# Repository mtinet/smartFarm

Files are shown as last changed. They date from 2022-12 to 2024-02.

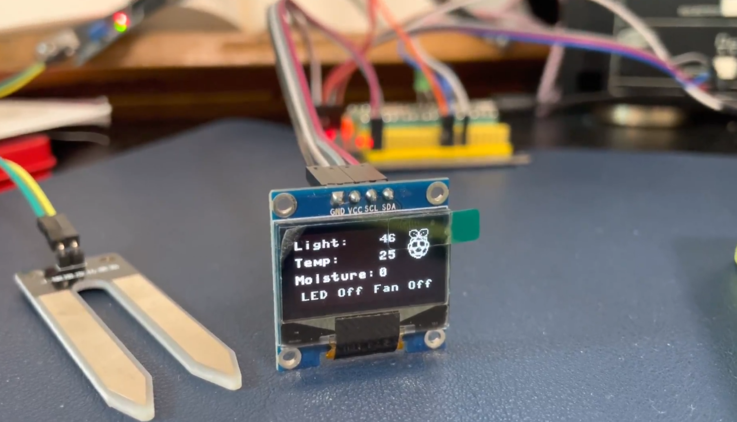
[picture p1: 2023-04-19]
0. image/testImage.png

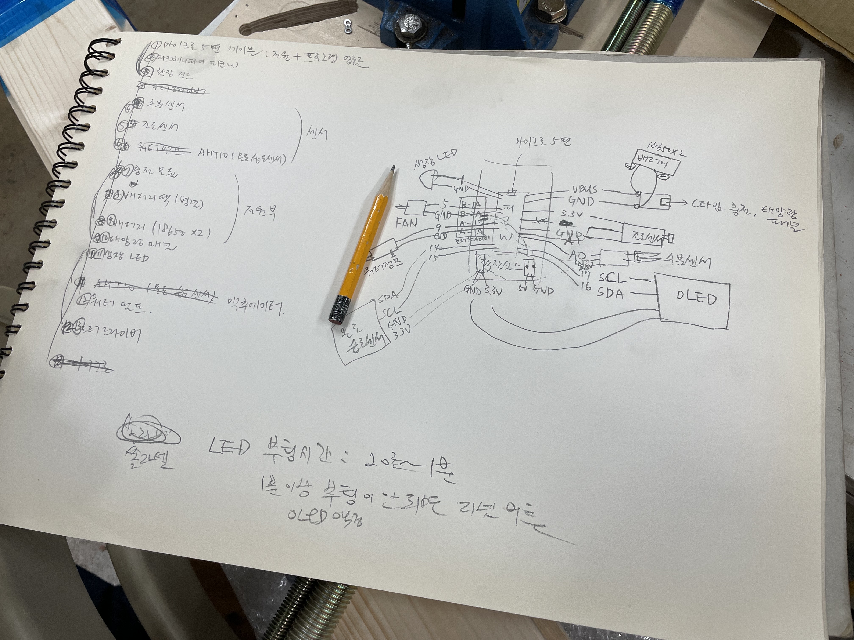
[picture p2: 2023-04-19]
0. image/design note.jpg

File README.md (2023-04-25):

# smartFarm
---

---
This code was written by Juhyun Kim.
---

## 강의 자료  
[http://han.gl/WLvoNj](http://han.gl/WLvoNj)  

---
## 구조
### Raspberry Pi Pico W - Firebase Realtime Database - Web or App  
#### 1. Firebase의 활용방법  
  

#### 2. 본 smartFarm의 운용 구조  


#### 3. 회로도  


---
---
## 각 세그먼트의 특징

### 1. Firebase  
#### 1. Firebase는 구글에서 운영하는 인터넷 관련 BaaS서비스라고 볼 수 있다. BaaS에 대한 정의는 [링크](https://blog.back4app.com/ko/%EC%84%9C%EB%B9%84%EC%8A%A4-%ED%98%95-%EB%B0%B1%EC%95%A4%EB%93%9Cbackend-as-a-service-baas%EB%8A%94-%EB%AC%B4%EC%97%87%EC%9D%B8%EA%B0%80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)를 참고한다. 각 온라인 서비스 프로바이더의 분류는 아래 그림을 참고하면 된다.  
  

#### 2. 우리가 스마트팜 프로젝트에서 Firebase를 사용하는 그 이유는 다음과 같다.  
* 첫째, 우리는 IPv4 시스템의 한계로 인해 개별 기기에 공인IP를 가질 수 없다.  
* 둘째, 이는 몇 개 안되는 공인IP 아래에 공유기를 연결해 사설 IP를 만들어내 사용해야 함을 의미한다.  
* 셋째, 사설 IP를 사용하는 디바이스가 운용하는 서비스에 접근하려면 네트워크의 개념을 이해하고 있어야 한다.
* 넷째, 이 중 가장 기본인 공인 IP에서 사설 IP로 연계를 하기 위한 과정인 포트포워딩에 대해 이해하고 있어야 한다.
* 다섯째, 모바일 통신에서는 각 모바일 통신사가 권한을 가지고 있는 모바일 통신망 NAT의 구조에 대해 이해하고 있어야 한다.
* 여섯째, 하지만 이를 도전한 사람들은 NAT를 통해 역으로 모바일 디바이스나 모바일 통신망을 통해 테더링을 하고 있는 디바이스에서 운용하는 서비스에 접근하는 것은 모바일 서비스를 제공하는 통신사의 권한부여 없이는 불가능하다는 사실을 수십 수백번의 시도 끝에 알게 된다. 통신사는 그걸 지원할 생각이 없다.
* 일곱째, 일반적으로 통신은 서버와 클라이언트로 구성되고, 서버가 서비스를 열면, 클라이언트가 접근하는 형태로 서비스가 되는데, 위의 설명과 같은 이유들로 서버가 서비스를 해도 클라이언트가 접근을 할 수가 없거나, 그 과정이 매우 어렵다는데 있다.
* 여덟째, 따라서, 우리는 구글 계정과 간단한 세팅만으로 쉽게 사용할 수 있는 Firebase라는 중간 단계의 Realtime Database 서비스를 이용해 이 곳에 데이터를 올리고, 이 곳에 접근해서 데이터를 읽어가는 형태의 서비스를 구상하게 된 것이다.
* 참고로, Firebase는 Realtime Database만 지원되는 것이 아니고, 인증, 앱체크, 데이터베이스, 스토리지, 호스팅, 함수 서비스, 머신러닝, 분석 등 엄청나게 다양한 서비스를 지원하고 있으며, 충분한 용량을 무료로 제공하므로, 개발단계나 테스트 단계에서는 무료라고 봐도 무방하다.
* 어쨌든 사람들이 해당 서비스를 사용하고, 그 서비스를 이용해 부가가치를 만들어내야 자신들도 먹고 살 수 있음을 잘 알고 있는 것이고, 그런 사람들이 많으면 많을수록 좋으니 이렇게 제공되는 기본 서비스들을 통해서 우리 같은 초보개발자들이 마음 놓고 테스트를 진행해볼 수 있다는 것이다.
* 이는 오픈소스 진영의 라이프사이클이 잘 돌아가고 있고, 그 안에 있는 사람들이 아직 건재하게 생존해 있다는 것으로 증명된 사실이며, 사실 구글도 그런 문화를 통해 성장해왔으니, 그런 서비스를 통해 자신들의 생태계를 더욱 확장하는 방법을 알고 있는 것은 어찌보면 매우 당연한 일이다.

---
### 2. Github Pages  
#### 1. Github는 전세계 코더들의 자료 저장소이며, 자신의 프로젝트들을 관리하고 공유할 수 있도록 서비스를 제공하고 있다.
#### 2. Github Pages는 HTML, CSS, JavaScript로 대변되는 정적 웹페이지에 대한 서비스를 무료로 제공하고 있다. 정적 웹페이지는 서버측에서 클라이언트의 특정한 요청에 대해 프로세스를 진행하고 그 결과물을 제공해주는 동적웹페이지(WAS서버, 데이터베이스, 로그인 기능 등이 추가됨)와 달리 단순히 웹페이지만 제공한다.
#### 3. 우리가 스마트팜 프로젝트에서 Github Pages를 사용하는 이유는 다음과 같다.
* 첫째, 이 프로젝트가 제공하는 것은 Firebase의 Realtime Database가 아니라 이를 활용하여 스마트팜의 정보를 지구 반대편에서도 확인하고 원격으로 제어할 수 있는 서비스이다.  
* 둘째, 서버에 클라이언트가 직접 접근할 수 있는 서비스가 가장 직관적이며 빠르지만, 서버를 스스로 구축하는 부분에 대한 개인 역량의 문제, 네트워크의 접근성 제약에 따른 한계 등 다양한 형태의 제약조건이 많으므로, 이를 극복하면서도 그럴싸한 서비스를 제공할 필요가 있다.  
* 셋째, Github Pages는 이러한 서비스를 제공하는데 가장 쉬운 서비스를 무료로 제공하고 있다.  
* 넷째, Github 자체는 전세계 사람들이 참여하고 있으므로, 이번 기회를 통해 이 생태계를 이해하게 된다면, 소프트웨어 관련 프로젝트를 진행할 때 든든한 지원군을 얻게 되는 셈이다.  
* 다섯째, 당연히 웹페이지도 무료로 배포되며, 자신만의 포트폴리오를 만들고 관리하는데 매우 훌륭한 도구이다.  
* 여섯째, 일단 웹페이지로 구현된 것은 WebViewer라는 기능을 통해 쉽게 앱으로도 구현할 수 있다.  
* 일곱째, 부수적으로 [W3Schools](https://www.w3schools.com/)등의 사이트를 Github와 함께 활용함으로써 웹을 이용한 서비스를 구축하는 다양한 방법들을 공부하고, 관련 역량을 키워나갈 수 있다.  

---
### 3. Raspberry Pi Pico W  
#### 1. Raspberry Pi Pico W는 아두이노 우노에 대응하는 라즈베리파이 재단의 피지컬 컴퓨팅 도구인 라즈베리파이 피코의 와이파이 버전이다.  
##### * [PicoW-A4-Pinout.pdf](https://github.com/mtinet/smartFarm/files/10328225/PicoW-A4-Pinout.pdf)  
##### * [핀 설명 자료](https://www.mischianti.org/2022/09/16/raspberry-pi-pico-w-high-resolution-pinout-and-specs/)  
##### * [Pico W 활용방법](https://make.e4ds.com/contest/board_view.asp?t=2&idx=653&ctidx=8)  
  

  

#### 2. 파이썬을 활용하므로 프로그래밍과 관련 생태계에 쉽게 접근이 가능하다.  
#### 3. 우리가 스마트팜 프로젝트에서 Raspberry Pi Pico W를 사용하는 이유는 다음과 같다.
* 첫째, 다른 라즈베리파이가 라즈비안이라는 리눅스 OS를 사용하는 컴퓨터(MPU, 마이크로 프로세서 유닛을 사용하는)인 반면에 피코는 펌웨어(파이썬 펌웨어, 자바스크립트 펌웨어 등)를 올려서 주로 피지컬 컴퓨팅용으로 사용하는 장비(MCU, 마이크로 컨트롤러를 사용하는)이다. 이는 아두이노 우노와 같은 반복적인 일을 하는데 최적화 되어 있음을 의미한다.
* 둘째, 아두이노 우노와의 차이점은 아두이노 우노의 경우 C, C++을 사용하므로 가볍게 사용할 수 있지만, 사용 언어가 요즘 세대에게 익숙하지 않다는 점이 있는데 반해 라즈베리파이 피코의 경우 어떤 펌웨어를 업로드 하느냐에 따라 마이크로 파이썬이나 자바스크립트 등을 선택해서 사용할 수 있고, 상대적으로 고급 언어를 사용할 수 있다는 점이 장점이다.
* 셋째, 마이크로 파이썬을 사용할 경우 [https://micropython.org/download/rp2-pico-w/](https://micropython.org/download/rp2-pico-w/) 링크에서 최신 버전을 다운로드 받은 다음 피코에 업로드 하면 된다. 업로드는 피코의 Bootsel 버튼을 누른 상태에서 컴퓨터에 USB케이블을 꽂으면 피코가 외장 디스크로 인식이 되고, 내 컴퓨터에서 다운로드 받은 펌웨어 파일을 업로드 하기만 하면 된다.
* 넷째, Pico W는 마이크로 컨트롤러이지만 WiFi모듈이 실장되어 있어, 주변에 와이파이 공유기가 있다면, 바로 공유기(2.4GHz)에 접속해 인터넷과 연결할 수 있다.  
* 다섯째, 조도, 온도, 습도 센서를 비롯한 다양한 형태의 센서로부터 값을 받아와서 Firebase로 전송이 가능하므로, 어떤 장치를 만들더라도 해당 시스템만 이해하고 있으면 확장이 가능하다.  
* 여섯째, 반도체 이슈 이후로 각 싱글보드 컴퓨터의 가격이 폭등하였는데, 피코는 여전히 저렴하다. 일반 피코는 4달러, 피코 W는 6달러 수준이고, 국내에서도 큰 차이 없이 구매할 수 있으므로, 더욱 매력적이다.  
* 일곱째, 블루투스를 이용한 스마트팜은 근거리에서만 활용이 가능하며 진정한 의미의 IoT라고 볼 수 없는데, 피코 W는 이점을 굉장히 쉬운 방법으로 극복할 수 있으며, ESP32, ESP8266보드에 비해서 사용성이 용이하다.

---
---
## 세그먼트 간 통신 테스트 영상

### Raspberry Pi Pico - Firebase - Github Pages(P5js)

#### 1. 웹페이지를 Github Pages에 올려 구동을 한 후 Firebase와 통신이 잘되는지 테스트  
https://user-images.githubusercontent.com/13882302/210140386-bab783f3-679c-4fcc-b290-30dfc66772a5.mp4

#### 2. P5js, Github Pages, Android WebViewer로 각각 접속하여 제어하는 테스트  
KakaoTalk_20221231_232533880  

https://user-images.githubusercontent.com/13882302/210140510-c865a007-dc22-45c3-a544-d3b83081fc7e.mp4

### Raspberry Pi Pico - Firebase - Github Pages(Gauge)
#### 1. Firebase - Github Pages  
https://user-images.githubusercontent.com/13882302/210126670-243a6fd7-b9b9-4378-b12e-63e5b2ef9260.mp4

#### 2. Raspberry Pi Pico W - Firebase - Github Pages 상호 연동 전체 테스트(센서 실측, 실물 액츄에이터 제어만 빠진 상태)  
https://user-images.githubusercontent.com/13882302/210160212-4c1c4434-d080-4d26-9ced-889305b29337.mp4  

#### 3. Pico에 연결되어 있는 엘이디의 초록색은 LED On, Fan Off, 하늘색은 LED On, Fan On, 파란색은 LED Off, Fan On, 꺼지면 LED Off, Fan Off
https://user-images.githubusercontent.com/13882302/210160762-b4973f54-8970-44d7-9b3c-84a1720f3988.mp4  

---
---
## 세팅

### 1.Firebase 세팅
#### 1. 아래 링크로 이동해서 구글 계정으로 로그인을 하고, 오른쪽 상단에 있는 '콘솔로 이동' 버튼을 눌러 Firebase 콘솔로 들어간다.  
[https://firebase.google.com/](https://firebase.google.com/)  


#### 2. '프로젝트 추가'버튼을 눌러 자신의 프로젝트를 만든다.  
  
  

#### 3. 데이터 분석을 하지 않을 경우 Google 애널리틱스 사용 설정을 해제하고 '프로젝트 만들기'버튼을 누른다.  
  
  

#### 4. 30초 정도 프로젝트 생성 시간을 기다린다.  
  
  
  

#### 5. 새로 만든 프로젝트 폴더로 들어간다.  
  

#### 6. Firebase 메뉴중에서 빌드-Realtime Database를 선택해서 연다.  
화면 캡처 2022-12-31 160136  

#### 7. '데이터베이스 만들기' 버튼을 누른다.  
  

#### 8. 서버 위치를 선택한다.  
  

#### 9. 데이터베이스 기본 설정을 한다. 추후 언제나 바꿀 수 있으니 기본 세팅으로 사용설정을 한다.  
  

#### 10. 가운데 있는 링크를 통해 Realtime Database에 접근을 할 수 있다.  
  

#### 11. '규칙' 탭으로 들어오면 데이터베이스에 대한 읽기, 쓰기 권한이 설정되어 있는데, 이 설정이 매우 중요하다.  
  

#### 12. false로 기본 설정되어 있는데, 이곳을 클릭하여 true로 바꿔주고 '게시'버튼을 누르면 누구나 접근해서 데이터를 읽고 쓸 수 있다. 추후 보안 및 트래픽에 따른 결제비용 증가에 영향을 줄 수 있으니, 테스트 할 때만 true로 설정하고, 실제 사용할 때는 읽고 쓰는 권한을 false로 바꾸고 접근한 사람의 사용자 권한에 따라 사용하거나, 엑세스 토큰을 부여받아 사용할 수 있도록 해야한다.  
  

#### 13. 다음으로 이 Realtime Database를 실제로 사용하기 위해서 관련 config 내용을 얻어야 한다. 프로젝트 개요-기어 버튼-프로젝트 설정으로 가서 내 웹앱에 firebase를 추가하는 버튼을 눌러 세팅을 완료하고, config 정보를 얻어낸다. 한 번 세팅을 완료하면 세팅을 삭제하기 전까지는 계속 해당 config를 사용할 수 있다.    
  

210127985-4958b729-b8d9-4291-88dd-9501b94bfc01  

210128004-1cfdf26e-da0b-4f69-9ae5-163931e758bd  

  

  

화면 캡처 2022-12-31 155100  

#### 14. firebase config 정보를 가져온다. 아래의 최종 이미지 안에 있는 firebaseConfig 내부의 값만 복사해서 내 웹의 web/public/js/firebase.js파일의 해당 부분에 붙여넣으면 자신의 Realtime Database에 접근해서 온도, 습도, 조도, LED제어, Fan제어를 위한 데이터를 주고 받는 smartFarm 제어용 웹 서비스를 바로 이용할 수 있다.
화면 캡처 2022-12-31 155119  

* Firebase 사용 요금제는 아래 링크를 참고하면 되며, 테스트 용도로는 비용이 따로 들지 않는다고 봐도 무방하다.  
[https://firebase.google.com/pricing?authuser=0&hl=ko](https://firebase.google.com/pricing?authuser=0&hl=ko)  

---
### 2. Web(github pages) 세팅  
* 테스트 링크  
[https://mtinet.github.io/smartFarm/web/public/index.html  ](https://mtinet.github.io/smartFarm/web/public/index.html)  

---
### 3. Raspberry Pi Pico W 세팅  
#### 1. 개발 IDE로는 [Thonny](https://thonny.org/)를 사용한다. [펌웨어 링크](https://micropython.org/download/rp2-pico/)로 들어가서 view raw를 눌러 펌웨어를 다운로드 받고, 피코 W의 bootsel버튼을 누르고 USB케이블을 연결하면 활성화되는 피코 폴더(파일관리자-내PC-피코 W 드라이브)에 복사해서 넣는다.  
#### 2. Thonny 설치 후 Run-Configure Interpreter-Interpreter에서 'MicroPython (Raspberry Pi Pico)'를 선택하고 연결된 Port를 선택해야 피코에 마이크로파이썬을 사용해 프로그래밍을 하여 업로드 할 수 있다.  
  
  
#### 3. 왼쪽 상단은 내 컴퓨터의 폴더와 파일, 왼쪽 하단은 피코 내부 메모리의 폴더와 파일, 가운데는 프로그래밍 공간, 가운데 하단은 파이썬 상태 체크용 콘솔이 위치한다.  
  
#### 4. 위쪽의 플레이 버튼과 정지 버튼을 통해 코드를 실행하고 멈춘다.  
#### 5. 코드의 저장은 내 컴퓨터에도 할 수 있고, 피코에도 할 수 있도록 선택해서 저장하고, 서로 업로드 다운로드가 된다.  
#### 5. 피코에 업로드 한 코드를 선택하고, 플레이 버튼을 누르면 피코 파이썬 펌웨어가 연산한 결과를 콘솔에 보여주게 된다.  
#### 6. 기본적으로 라이브러리를 설치해서 사용할 수는 있으나 피코의 저장 가능 용량이 800kB밖에 안되서 용량이 큰 라이브러리는 사용할 수 없다.  
#### 7. 따라서 Firebase 인증 토큰을 발급받는데 사용하는 라이브러리를 쓸 수 없고, Firebase RTDB의 규칙을 false로 해 놓을 경우 토큰을 통한 쓰기, 읽기 권한을 획득할 방법이 없어 규칙을 항상 true로 해놓고 사용해야 하는 불편함이 있다. 추후 피코의 내부 메모리 용량이 늘어난 제품이 나오면 해결될 문제로 보인다.  
#### 8. pico 폴더 안에 있는 boot.py, main.py파일을 다운로드 받아 Thonny를 이용해 자신의 피코에 업로드 한 다음 상단의 플레이 버튼을 누릅니다.
#### 9. Thonny로 실행을 하면 각각의 파일들을 원하는대로 실행할 수 있지만, 아두이노처럼 전원을 넣으면 바로 해당 코드가 실행되게 하기 위해서는 파일명을 반드시 main.py로 지정해줘야 합니다.
#### 10. boot.py 파일은 피코가 잘 부팅이 되고 있는지를 시각적으로 확인하기 위해서 원래 피코의 boot과정을 약간 수정해 놓은 파일이라고 생각하면 됩니다.  
  

* boot.py
```python
from machine import Pin
from utime import sleep

led = Pin(27, Pin.OUT)

led.on()
sleep(0.2)
led.off()
sleep(0.2)
led.on()
sleep(0.2)
led.off()
sleep(0.2)
led.on()
sleep(0.2)
led.off()
sleep(0.2)

import main
```
#### 11. 아래 캡쳐의 17번째 줄 wlan.connect의 파라메터에는 자신의 와이파이 SSID, Password를 입력해 놓으면 자동으로 와이파이에 접속이 됩니다. 27번째줄 url에는 자신이 만든 Firebase RTDB의 주소로 수정해주세요.  
  

#### 12. 아래 코드는 조도, 온도, 수분 값을 랜덤으로 생성해서 보내도록 세팅해놨습니다. 추후 실제 센서를 테스트 하여 코드를 수정할 예정입니다.
* base.py
```python
from machine import Pin, I2C
import network
import time
import urequests
import random

# 제어할 핀 번호 설정
from machine import Pin
led = Pin(26, Pin.OUT)
fan = Pin(27, Pin.OUT)

# 와이파이 연결하기
wlan = network.WLAN(network.STA_IF)
wlan.active(True)
if not wlan.isconnected():
    wlan.connect("<SSID>", "<Password>")
    print("Waiting for Wi-Fi connection", end="...")
    while not wlan.isconnected():
        print(".", end="")
        time.sleep(1)
else:
    print(wlan.ifconfig())
    print("WiFi is Connected")

# RTDB주소
url = "<자신의 Firebase RTDB주소>"

# DB 내역 가져오기
response = urequests.get(url+".json").json()
# byte형태의 데이터를 json으로 변경했기 때문에 메모리를 닫아주는 일을 하지 않아도 됨
# print(response)
# print(response['smartFarm'])
# print(response['smartFarm']['led'])

while True:
    # 현재 DB의 정보를 가져옴
    response = urequests.get(url+".json").json()
    # 현재 DB의 led 키 값의 상태에 따라 led 26번을 제어
    if (response['smartFarm']['led'] == 0) :
        led.value(1)
    else :
        led.value(0)

    # 현재 DB의 fan 키 값의 상태에 따라 led 27번을 제어
    if (response['smartFarm']['fan'] == 0) :
        fan.value(1)
    else :
        fan.value(0)

    # 객체 교체하기, patch는 특정 주소의 데이터가 변경됨
    myobj = {'light': random.randrange(0, 100), 'temp': random.randrange(0, 50), 'mois': random.randrange(0,100)}
    urequests.patch(url+"smartFarm.json", json = myobj).json()
```
#### 13. pico 폴더에 있는 main.py파일과 ssd1306.py파일을 pico w에 함께 넣어야 OLED로 모니터링이 됩니다.  
#### 14. main.py, main(non_OLED).py 파일은 Firebase의 값에 따라 LED, Fan을 제어하고, 센서로부터 측정된 Moisture, Temperature, Light값을 Firebase로 보낼 수 있도록 세팅 되어 있습니다.  

#### 15. 아래 이미지를 클릭하면 최종 테스트 영상으로 넘어갑니다.  
[](https://photos.google.com/share/AF1QipPdZMQIuR6TbsuhAgzuiSDbi6S7oMbunZZFA7i8bEVHT8tvyCN1nLGigmS2tvqPVQ/photo/AF1QipNA8Qm0aDRLaN9r_u2-HEUlCFJ6J7ueXP8NmX5M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)

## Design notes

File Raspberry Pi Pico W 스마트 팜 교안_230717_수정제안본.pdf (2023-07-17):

# 라즈베리 파이 피코 W를 활용한 IoT 스마트 팜 만들기

목차

1. 이론

### 1) 라즈베리 파이 피코(Raspberry Pi Pico)

### (1) 라즈베리 파이 피코 알아보기

### (2) 라즈베리 파이 피코 W

### (3) 사용 시 참고할 문서 및 예제

### 2) IoT 스마트 팜

### (1) 스마트 팜 작동 구조

### (2) 스마트 팜 부품 구성도

### (3) 스마트 팜에 사용되는 부품

2. 실습

### 1) 파일 내려 받기

### (1) 스마트 팜 소스 코드 내려 받기

### (2) 라즈베리 파이 피코 W 펌웨어 설치

### 2) 통합개발환경(IDE) Thonny

### (1) Thonny 설치

### (2) Thonny 인터프리터 설정

### (3) Thonny 화면 구성

### (4) Thonny 사용 방법

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
### 3) 회로 구성

### (1) 확장 쉴드 결합

### (2) 센서 모듈 연결

### (3) 식물 생장 LED, OLED 연결

### (4) 모터 연결

### (5) 전원 연결

### 4) 소스 코드

### (1) 사용되는 소스 코드

### (2) 소스 코드 수정

### (3) 소스 코드 업로드

### 5) Firebase

### (1) Firebase 프로젝트 만들기

### (2) 데이터베이스 만들기

### (3) 데이터베이스 config 정보 얻기

### 6) GitHub Pages

### (1) 컴퓨터에서 직접 웹페이지 서비스하기

### (2) GitHub repository 만들기

### (3) GitHub Pages 사용 설정하기

### 7) 최종 작동 확인

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
# 라즈베리 파이 피코 알아보기

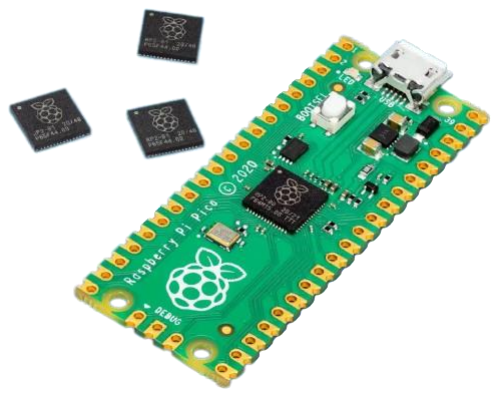
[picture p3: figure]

라즈베리 파이 피코는 영국의 라즈베리 파이 재단에서 개발한 RP2040 칩을 탑재해 C언어나 마이크로파이썬(MicroPython) 등의 프로그래밍 언어로 동작하도록 한 가정·산업용 마이크로컨트롤러 보드이다.

* 마이크로컨트롤러: 마이크로프로세서와 입출력 장치를 하나의 칩으로 만들어 정해진 기능을 수행하도록 한 컴퓨터

여러 소프트웨어를 구동하도록 설계된 운영체제(OS)가 들어가는 라즈베리 파이와는 달리, 라즈베리 파이 피코에는 펌웨어가 들어간다. 이 때문에 성능은 상용 PC에 비해 낮으나 단순하고 반복적인 동작을 수행하는 피지컬 컴퓨팅에 최적화되어 있다.

4 | 1. 이론 ― 1) 라즈베리 파이 피코

전원 핀(3V3, GND)으로 센서와 액추에이터에 전원을 공급하고 GPIO(다용도 입출력) 핀으로 센서나 액추에이터와 전기 신호를 주고 받을 수 있다. 프로그래밍 언어로 작성된 소스 코드를 업로드하면 센서의 측정 값을 읽거나 LED 점등, 모터 회전 등의 동작을 수행할 수 있다.

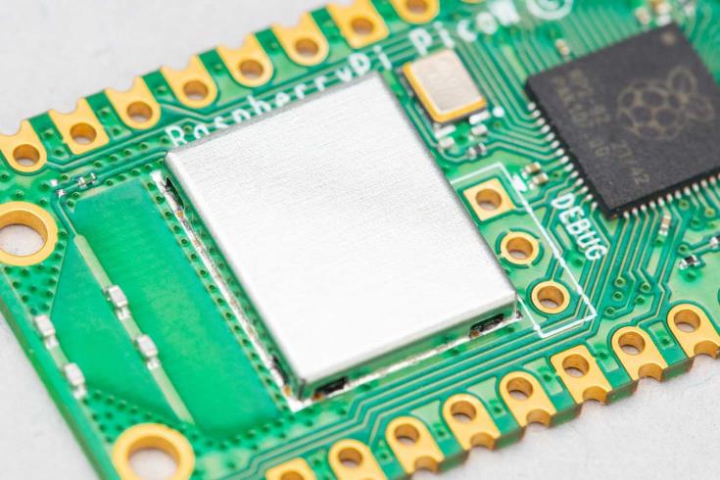
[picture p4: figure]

라즈베리 파이 피코 W는 무선 통신이 필요한 IoT 애플리케이션 및 프로젝트를 위해 라즈베리 파이 피코에 2.4 GHz 802.11n 무선 LAN을 탑재한 버전이다. 무선 LAN이 탑재되어 있어 Wi-Fi 연결(2.4 GHz)이 가능하고 인터넷에도 접속하여 세계 어디에서나 라즈베리 파이 피코 W를 통해 제어하도록 할 수도 있다.

라즈베리 파이 피코와는 무선 LAN이 탑재된 것을 제외하고는 마이크로컨트롤러(RP2040), 플래시 메모리 용량 등의 사양이 모두 동일하고 GPIO 핀의 개수와 구성도 똑같다. 따라서 라즈베리 파이 피코에서 작동하는 소스 코드를 피코 W에 그대로 붙여 넣고 Wi-Fi를 사용하는 기능을 추가할 수도 있다.

# 라즈베리 파이 피코 W

5 | 1. 이론 ― 1) 라즈베리 파이 피코

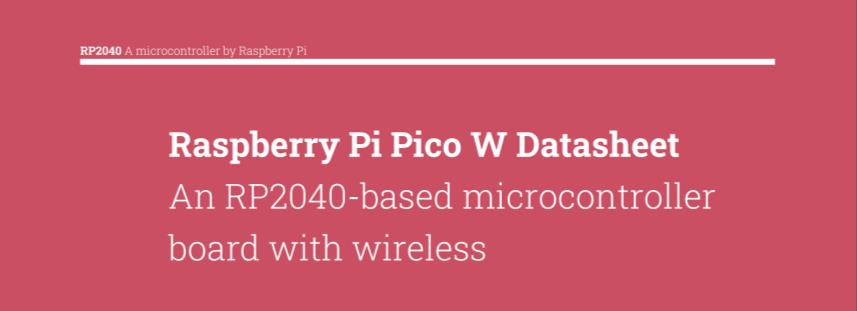
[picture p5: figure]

https://datasheets.raspberrypi.com/picow/pico-w-datasheet.pdf

라즈베리 파이 피코 W의 설계 파일, 기계적 사양, 응용 프로그램 정보 등을 적은 데이터시트

https://www.raspberrypi.com/documentation/microcontrollers/raspberry-pi-pico.html

라즈베리 파이 피코와 피코 W의 사용 방법을 설명하는 라즈베리 파이 재단의 공식 문서

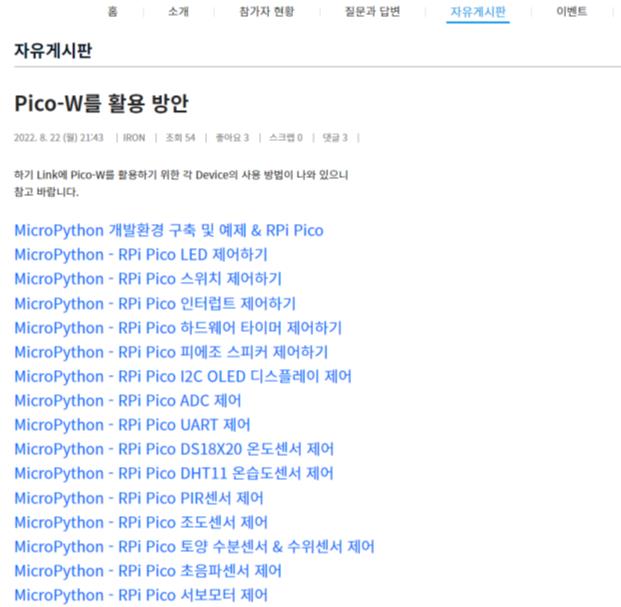
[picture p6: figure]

https://make.e4ds.com/contest/board_view.asp?idx=653&ctidx=8

라즈베리 파이 피코 W로 각종 센서와 액추에이터를 제어하는 방법을 설명하는 문서

# 사용 시 참고할 문서 및 예제

6 | 1. 이론 ― 1) 라즈베리 파이 피코

# 스마트 팜 작동 구조

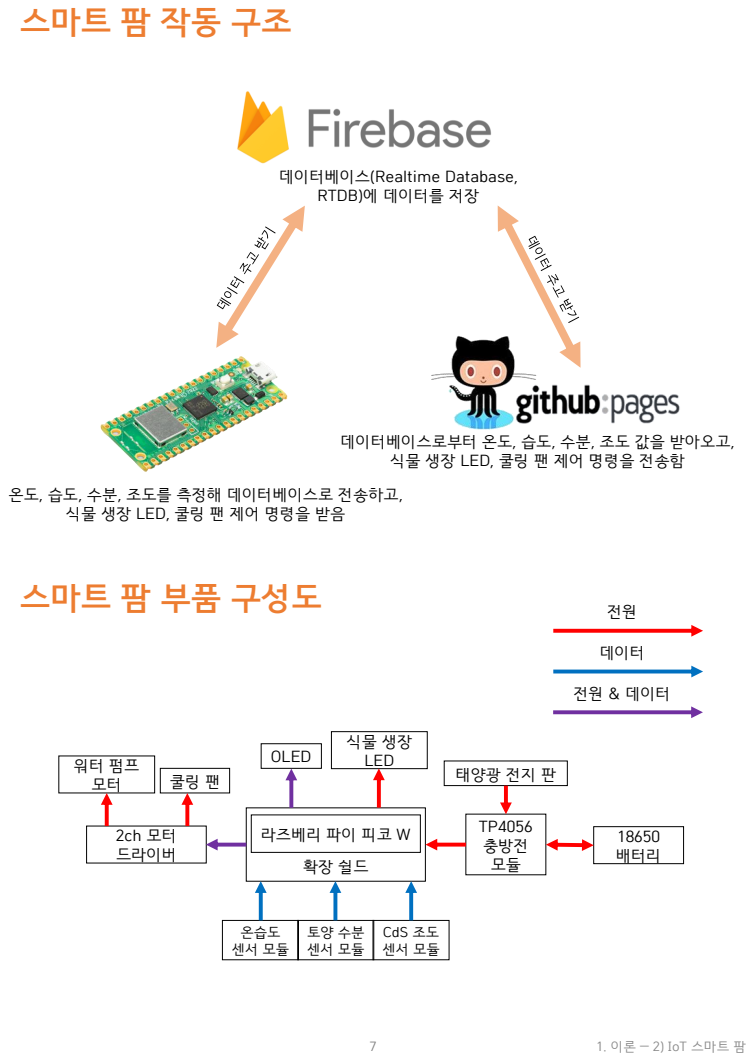
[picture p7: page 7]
데이터; 전원 & 데이터; 라즈베리 파이 피코 W; 드라이버; 식물 생장 LED; 18650 배터리; TP4056 충방전 모듈; 태양광 전지 판; OLED; 온습도 센서 모듈; CdS 조도 센서 모듈; 1. 이론 ― 2) IoT 스마트 팜

데이터베이스(Realtime Database,
RTDB)에 데이터를 저장

데이터베이스로부터 온도, 습도, 수분, 조도 값을 받아오고,

식물 생장 LED, 쿨링 팬 제어 명령을 전송함

온도, 습도, 수분, 조도를 측정해 데이터베이스로 전송하고,

식물 생장 LED, 쿨링 팬 제어 명령을 받음

스마트 팜 부품 구성도

라즈베리 파이 피코 W

피코 확장 쉴드

OLED(I2C 타입)

식물 생장 LED

Python 프로그램을 통해 각종 센서와 액추에이터를 GPIO 핀에 연결하여 제어하고 인터넷에 연결하여 데이터베이스와 데이터를 주고 받는다.

라즈베리 파이 피코를 결합해 GPIO 핀을 확장한다.

I2C 통신으로 피코 W로부터 데이터를 받아 화면에 표시한다.

실내에서 식물을 재배할 때 부족한 햇빛을 대체한다.

토양 수분 센서 모듈

CdS 조도 센서 모듈

온습도 센서 모듈(AHT10)

흙에 꽂아 저항 값을 측정해 흙에 포함된 수분이 얼마나 많은지를 측정한다.

광자 양이 많으면 저항 값이 낮아지고 광자 양이 적으면 저항 값이 높아지는 황화 카드뮴(CdS)의 특성을 이용해 조도를 측정한다.

측정된 온도와 습도 값을 I2C 통신을 통해 전송한다.

# 스마트 팜에 사용되는 부품

8 | 1. 이론 ― 2) IoT 스마트 팜

# 스마트 팜에 사용되는 부품

2ch 모터 드라이버

워터 펌프 모터

쿨링 팬

날개를 회전시켜 액체에 회전력을 주어
액체의 위치를 바꾼다.

모터의 회전 방향, 회전 속도 등을 입력 받아 모터를 제어한다.

날개를 회전시켜 바람을 일으킨다.

충방전 모듈(TP4056)

18650 배터리(+홀더)

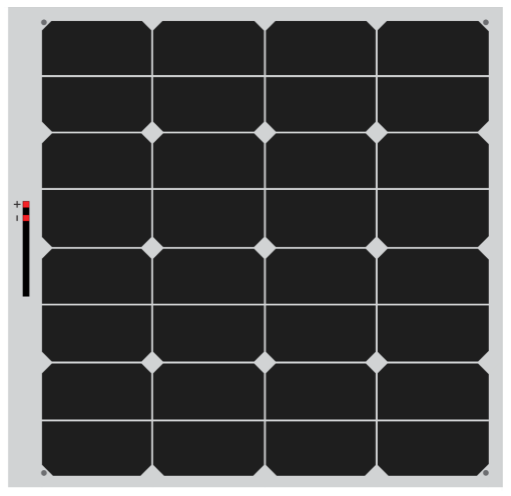
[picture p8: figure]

태양광 전지 판

반도체의 광전효과를 이용해 태양빛을 전기 에너지로 변환한다.

리튬 이온 배터리로, 전기 에너지를 모아 두었다가 필요할 때 출력한다.

USB 포트를 통해 리튬 이온 배터리를 충전하고 리튬 이온 배터리의 전기 에너지를 외부에 연결된 장치로 출력한다.

9 | 1. 이론 ― 2) IoT 스마트 팜

# 스마트 팜 소스 코드 내려 받기

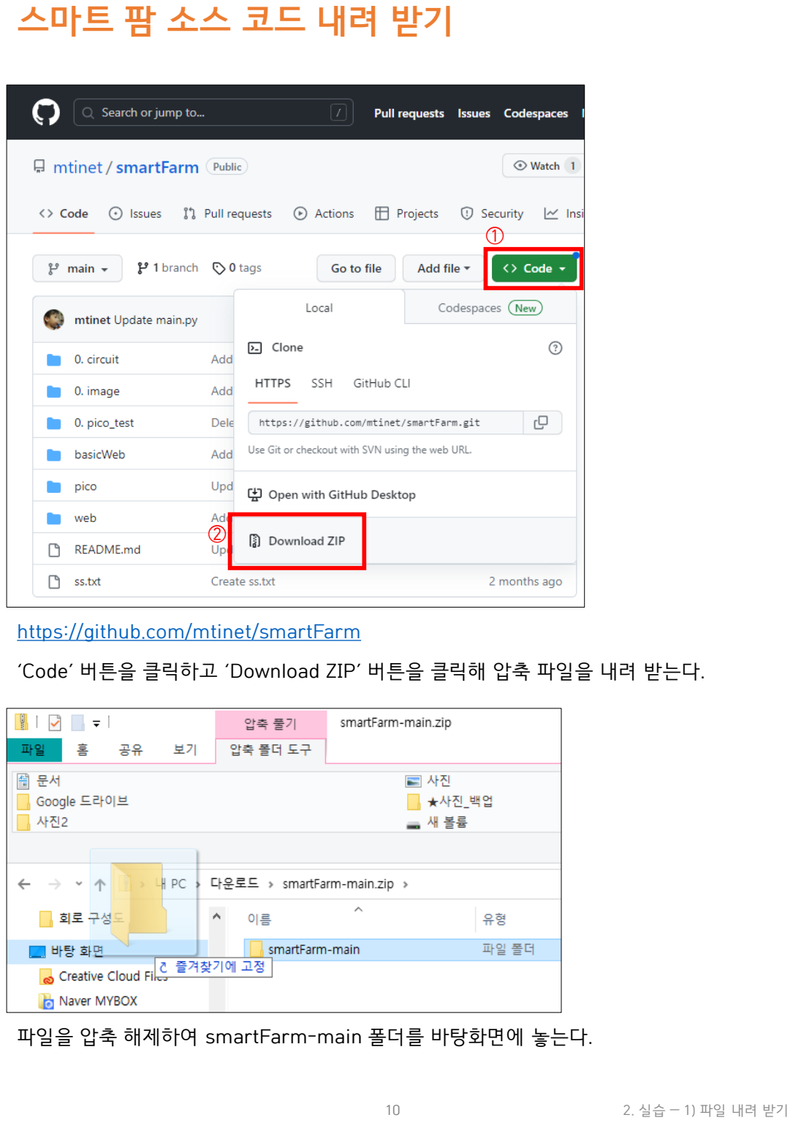
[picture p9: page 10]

https://github.com/mtinet/smartFarm

‘Code’ 버튼을 클릭하고 ‘Download ZIP’ 버튼을 클릭해 압축 파일을 내려 받는다.

파일을 압축 해제하여 smartFarm-main 폴더를 바탕화면에 놓는다.

10 | 2. 실습 ― 1) 파일 내려 받기

②

①

https://micropython.org/download/rp2-pico-w/

라즈베리 파이 피코 W에 탑재되는 펌웨어(.uf2 파일)를 내려 받는다.

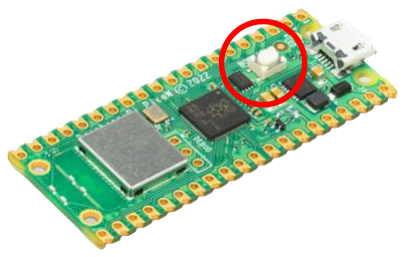
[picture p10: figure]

보드의 bootsel 버튼을 누른 채로 USB 케이블로 컴퓨터와 연결한다.

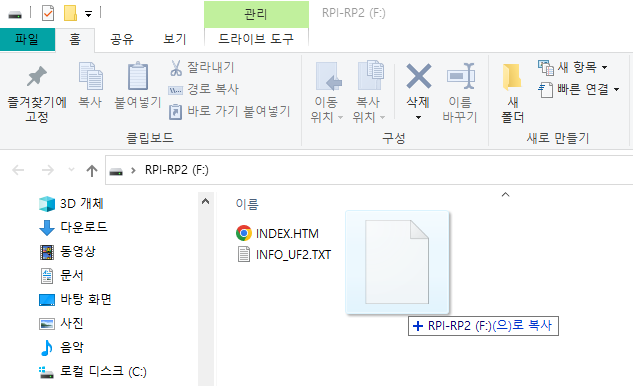
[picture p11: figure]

피코 W 폴더(내 PC → ‘RPI-RP2’ 드라이브)에 펌웨어 파일을 붙여 넣는다.

# 라즈베리 파이 피코 W 펌웨어 설치

11 | 2. 실습 ― 1) 파일 내려 받기

라즈베리 파이 피코에는 프로그래밍 언어로 작성된 소스 코드를 업로드해야 한다. Thonny는 마이크로파이썬으로 소스 코드를 작성하고 라즈베리 파이 피코로 실행 및 업로드할 수 있도록 하는 파이썬 용 통합 개발 환경(IDE)이다.

Thonny는 라즈베리 파이 피코 개발을 위한 마이크로파이썬 인터프리터와 모듈이 사전에 설치 되어 있어 Thonny 하나만 설치하면 피코 W 사용에 필요한 환경을 한 번에 구축할 수 있다.

# Thonny 설치

https://thonny.org/

Thonny의 최신 버전을 내려 받아 설치한다.

12 | 2. 실습 ― 2) 통합개발환경(IDE) Thonny

# Thonny 인터프리터 설정

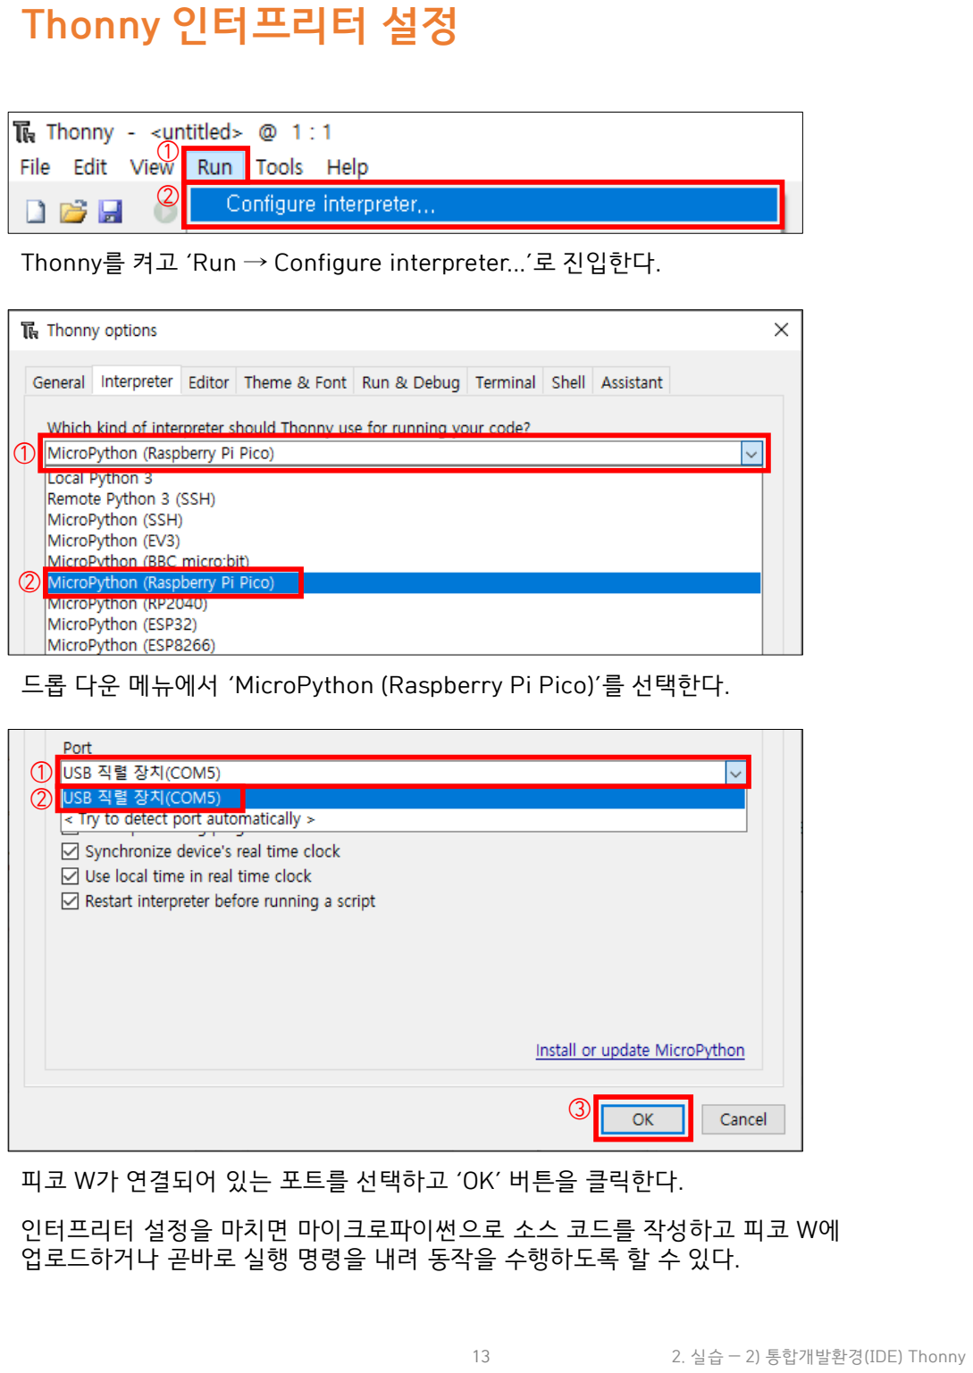
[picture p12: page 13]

Thonny를 켜고 ‘Run → Configure interpreter...’로 진입한다.

드롭 다운 메뉴에서 ‘MicroPython (Raspberry Pi Pico)’를 선택한다.

피코 W가 연결되어 있는 포트를 선택하고 ‘OK’ 버튼을 클릭한다.

인터프리터 설정을 마치면 마이크로파이썬으로 소스 코드를 작성하고 피코 W에 업로드하거나 곧바로 실행 명령을 내려 동작을 수행하도록 할 수 있다.

13 | 2. 실습 ― 2) 통합개발환경(IDE) Thonny

①

②

①

②

①
②

③

# Thonny 화면 구성 & 사용 방법

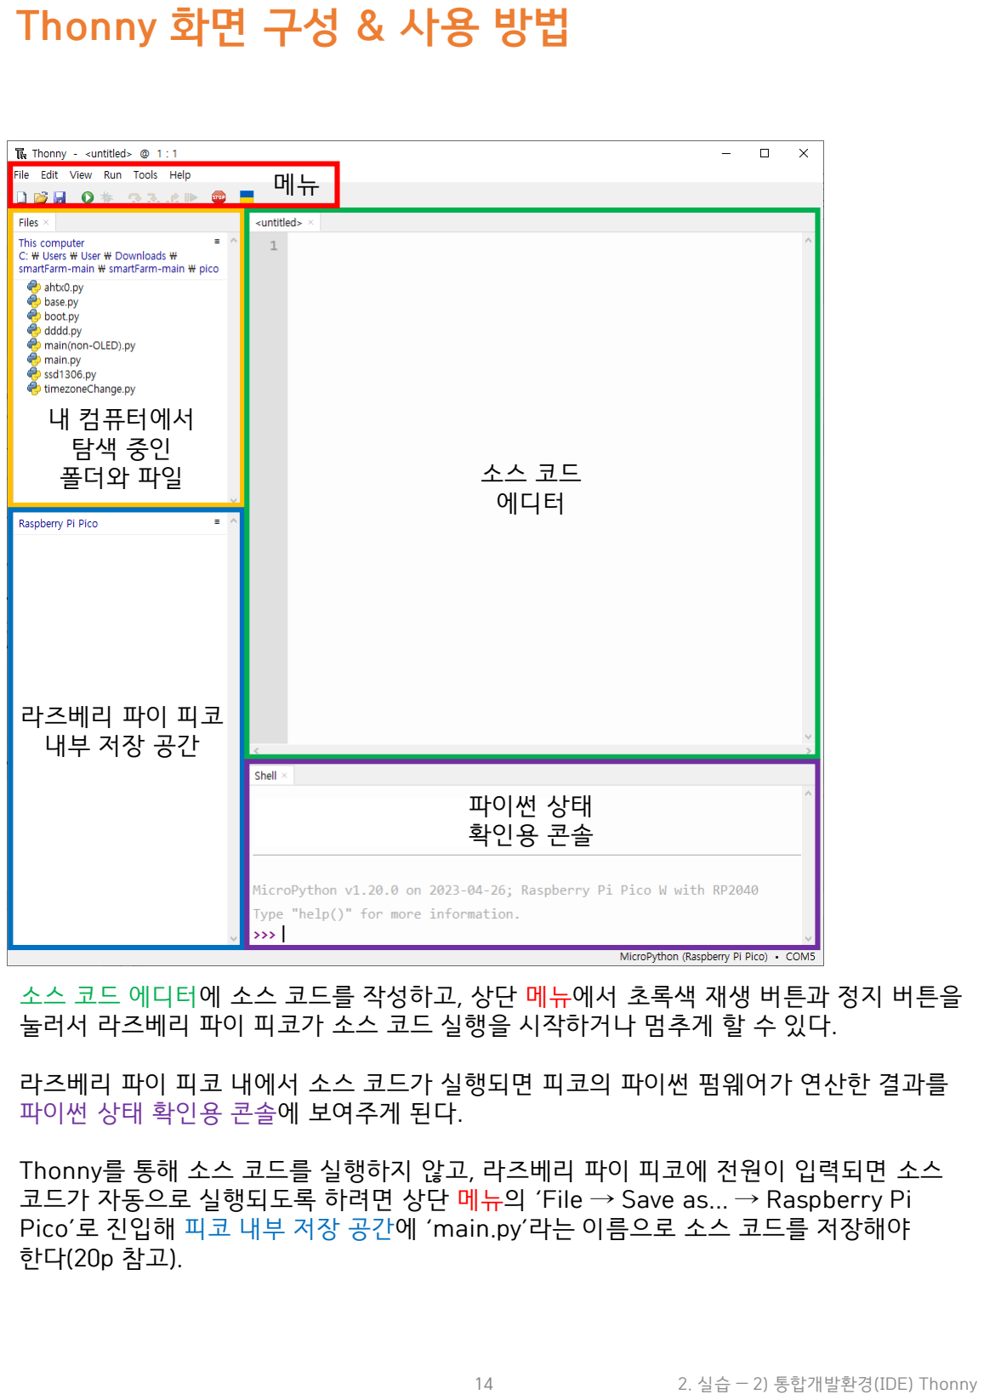
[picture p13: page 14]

14 | 2. 실습 ― 2) 통합개발환경(IDE) Thonny

소스 코드 에디터에 소스 코드를 작성하고, 상단 메뉴에서 초록색 재생 버튼과 정지 버튼을 눌러서 라즈베리 파이 피코가 소스 코드 실행을 시작하거나 멈추게 할 수 있다.

라즈베리 파이 피코 내에서 소스 코드가 실행되면 피코의 파이썬 펌웨어가 연산한 결과를 파이썬 상태 확인용 콘솔에 보여주게 된다.

Thonny를 통해 소스 코드를 실행하지 않고, 라즈베리 파이 피코에 전원이 입력되면 소스 코드가 자동으로 실행되도록 하려면 상단 메뉴의 ‘File → Save as... → Raspberry Pi Pico’로 진입해 피코 내부 저장 공간에 ‘main.py’라는 이름으로 소스 코드를 저장해야 한다(20p 참고).

내 컴퓨터에서
탐색 중인
폴더와 파일

라즈베리 파이 피코
내부 저장 공간

소스 코드
에디터

파이썬 상태
확인용 콘솔

메뉴

# 회로 구성 ― 확장 쉴드 결합

① 피코 W 확장 쉴드에 피코 W를 결합
※ 쉴드 윗면 프린팅을 참고하여 피코 W의 방향 확인

② 온습도 센서 모듈의 SDA를 피코 W의 GP14에, 온습도 센서 모듈의 SCL을 피코 W의 GP15에, 온습도 센서 모듈의 GND를 피코 W의 GND에, 온습도 센서 모듈의 VIN을 피코 W의 3V3에 연결

③ 토양 수분 센서 모듈의 A0을 피코 W의 GP26(A0)에, 토양 수분 센서 모듈의 GND를 피코 W의 GND에, 토양 수분 센서 모듈의 VCC를 피코 W의 3V3에 연결

④ CdS 조도 센서 모듈의 A0을 피코 W의 GP27(A1)에, CdS 조도 센서 모듈의 GND를 피코 W의 GND에, CdS 조도 센서 모듈의 VCC를 피코 W의 3V3에 연결

# 회로 구성 ― 센서 모듈 연결

15 | 2. 실습 ― 3) 회로 구성

# 회로 구성 ― 식물 생장 LED, OLED 연결

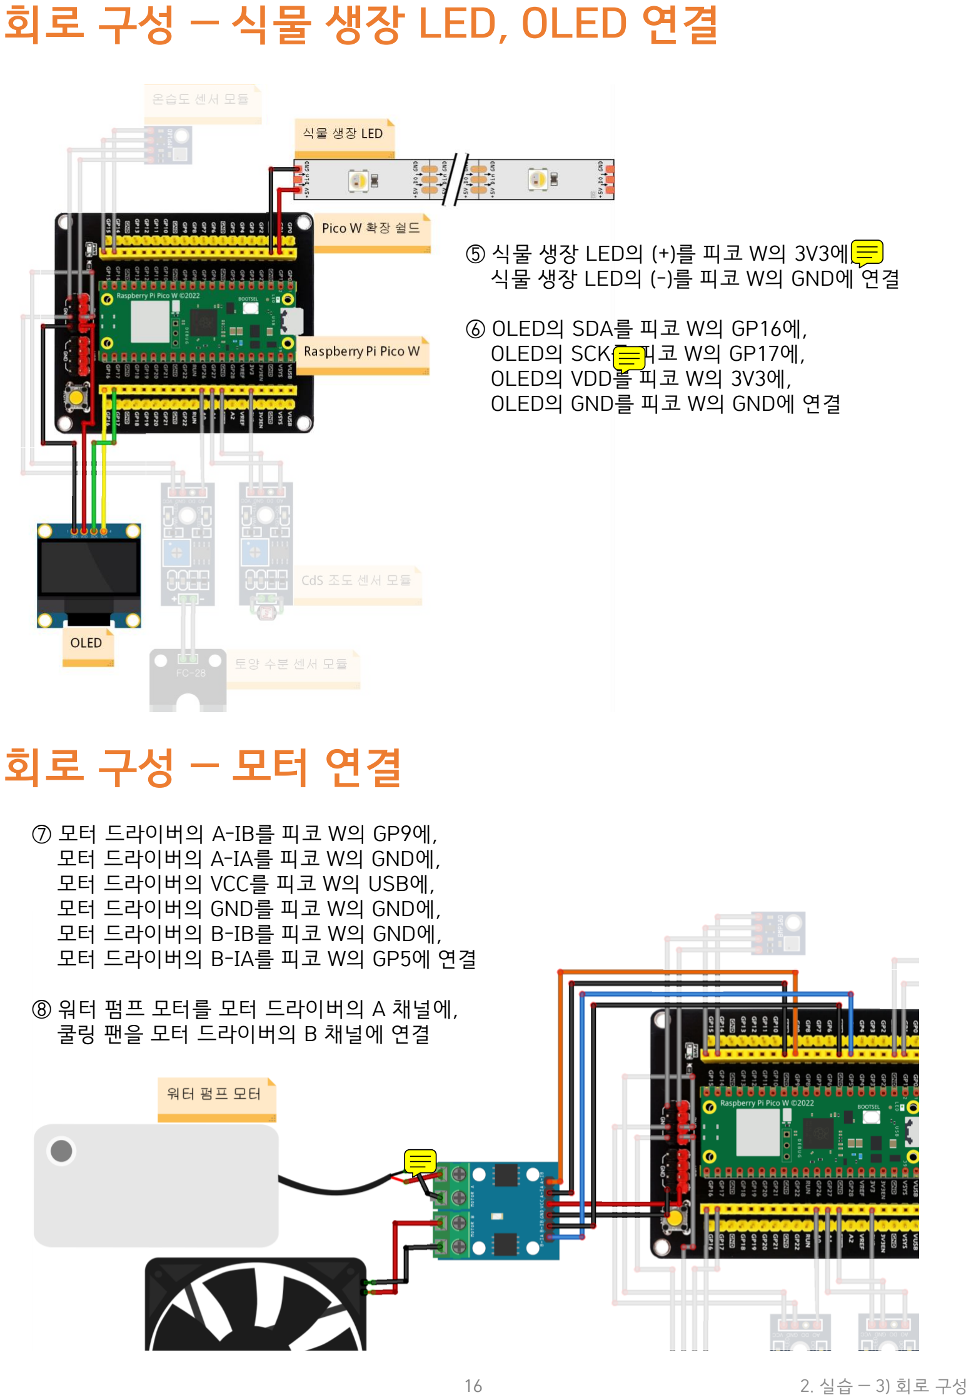
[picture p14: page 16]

⑤ 식물 생장 LED의 (+)를 피코 W의 3V3에, 식물 생장 LED의 (-)를 피코 W의 GND에 연결

⑥ OLED의 SDA를 피코 W의 GP16에,
OLED의 SCK를 피코 W의 GP17에,
OLED의 VDD를 피코 W의 3V3에,
OLED의 GND를 피코 W의 GND에 연결

⑦ 모터 드라이버의 A-IB를 피코 W의 GP9에, 모터 드라이버의 A-IA를 피코 W의 GND에, 모터 드라이버의 VCC를 피코 W의 USB에,
모터 드라이버의 GND를 피코 W의 GND에,
모터 드라이버의 B-IB를 피코 W의 GND에, 모터 드라이버의 B-IA를 피코 W의 GP5에 연결

⑧ 워터 펌프 모터를 모터 드라이버의 A 채널에, 쿨링 팬을 모터 드라이버의 B 채널에 연결

# 회로 구성 ― 모터 연결

16 | 2. 실습 ― 3) 회로 구성

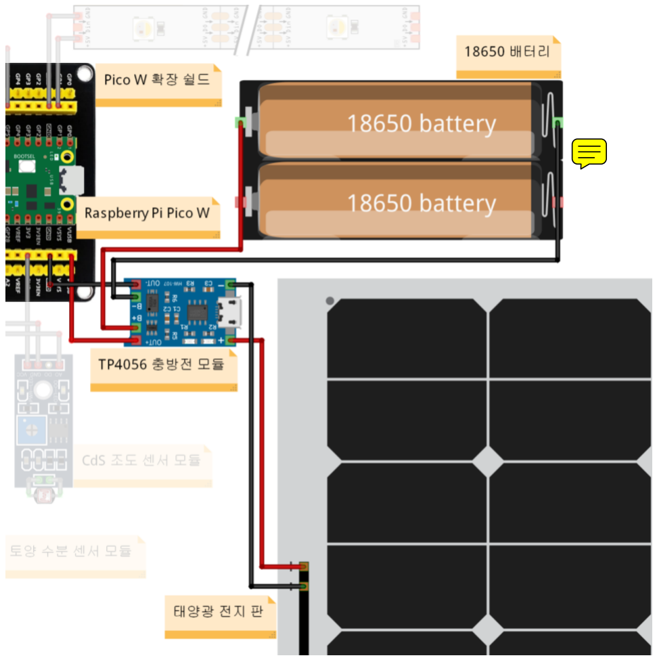
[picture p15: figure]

⑨ 충방전 모듈의 OUT-를 피코 W의 GND에,
충방전 모듈의 OUT+를 피코 W의 VUSB에 연결

⑩ 18650 배터리 홀더의 (+)를 충방전 모듈의 B+에, 18650 배터리 홀더의 (-)를 충방전 모듈의 B-에 연결

⑪ 태양광 전지 판의 (+)를 충방전 모듈의 (+)에,
태양광 전지 판의 (-)를 충방전 모듈의 (-)에 연결

# 회로 구성 ― 전원 연결

17 | 2. 실습 ― 3) 회로 구성

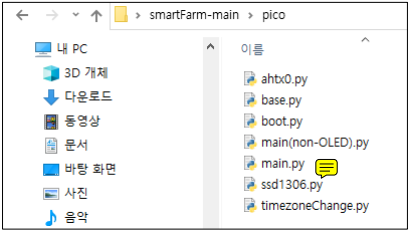
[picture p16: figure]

바탕화면에 내려 받았던(10p 참고) smartFarm-main 폴더의 ‘pico’ 폴더에 진입한다.

- base.py: 데이터베이스(Firebase RTDB)에 데이터를 랜덤 값으로 업로드하는 코드
- boot.py: 전원을 켰을 때 가장 먼저 실행되는 보드 설정 코드
- main(non-OLED).py: OLED를 사용하지 않는 스마트 팜의 메인 실행 코드
- main.py: OLED를 사용하는 스마트 팜의 메인 실행 코드
- ssd1306.py: OLED를 사용하기 위한 모듈 파일(OLED 사용 시 같이 업로드)

OLED를 사용하는 경우: boot.py, main.py, ssd1306.py가 필요
OLED를 사용하지 않는 경우: boot.py, main(non-OLED).py가 필요

파일을 열 때는 파일을 우클릭한 후 ‘연결 프로그램(H) → Thonny’를 선택한다.

# 사용되는 소스 코드

18 | 2. 실습 ― 4) 소스 코드

base.py, main(non-OLED).py, main.py가 보드에 업로드 되면, 피코 W에 전원이 입력되었을 때 자동으로 소스 코드가 실행된다. 그 전에 피코 W가 연결할 Wi-Fi 공유기의 SSID(이름)와 패스워드를 수정해야 하며, Firebase RTDB의 주소도 수정해야 한다.
※ Firebase RTDB의 주소: 23p ‘데이터베이스 만들기‘에서 확인

# 소스 코드 수정

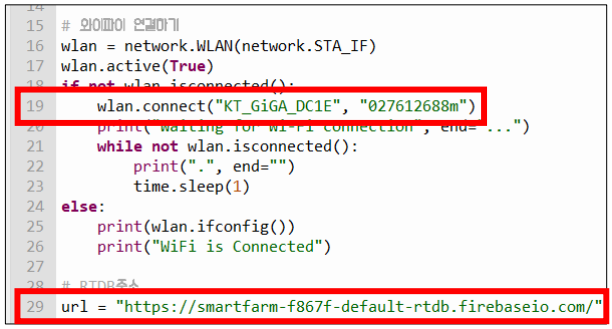
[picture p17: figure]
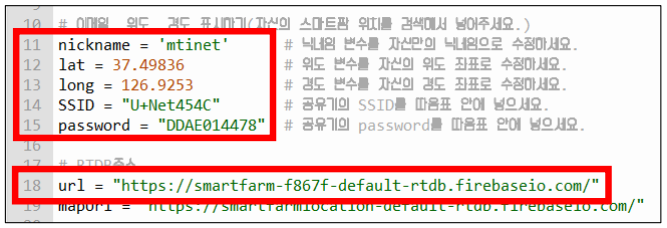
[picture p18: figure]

19 | 2. 실습 ― 4) 소스 코드
- base.py: 19, 29번째 줄 수정
- main(non-OLED).py: 14~15, 18번째 줄 수정
- main.py: 15~16, 24번째 줄 수정

파이썬 파일(.py)을 연 상태에서 ‘File → Save as...’로 진입한다.

‘Raspberry Pi Pico’를 선택한다.

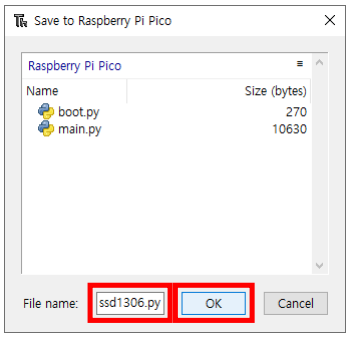
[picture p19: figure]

피코 W에 업로드 할 각각의 파일에 대하여 위 과정을 수행한다.
OLED를 사용하는 경우: boot.py, main.py, ssd1306.py가 필요
OLED를 사용하지 않는 경우: boot.py, main(non-OLED).py가 필요

피코 W에 업로드된 파이썬 소스 코드는 피코 W에 전원이 입력됐을 때 자동으로 실행된다.

File name에 파일 이름을 확장자명(.py)까지 적고 ‘OK’ 버튼을 클릭한다.
※ main(non-OLED).py 파일은 저장할 때 파일 이름을 ‘main.py’로 저장하여야 함

20

# 소스 코드 업로드

2. 실습 ― 4) 소스 코드

# Firebase 프로젝트 만들기

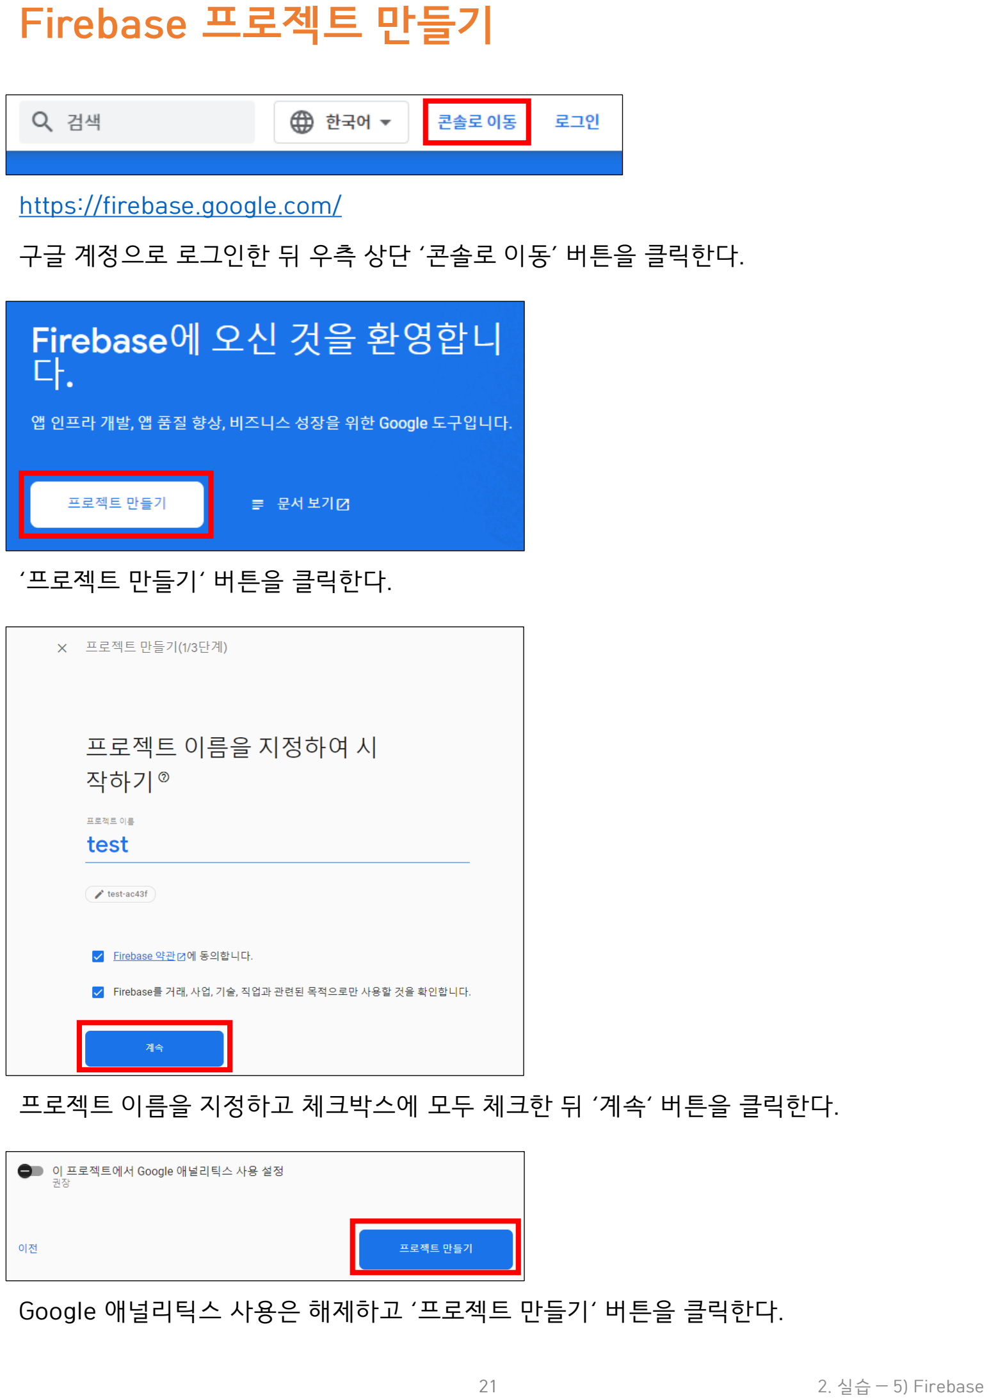
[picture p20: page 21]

https://firebase.google.com/

구글 계정으로 로그인한 뒤 우측 상단 ‘콘솔로 이동’ 버튼을 클릭한다.

‘프로젝트 만들기‘ 버튼을 클릭한다.

프로젝트 이름을 지정하고 체크박스에 모두 체크한 뒤 ‘계속‘ 버튼을 클릭한다.

Google 애널리틱스 사용은 해제하고 ‘프로젝트 만들기‘ 버튼을 클릭한다.

21 | 2. 실습 ― 5) Firebase

# 데이터베이스 만들기

데이터베이스의 물리적 위치를 선택하고 ‘다음‘ 버튼을 클릭한다.

‘잠금 모드로 시작’으로 놔두고 ‘사용 설정’ 버튼을 클릭한다.
※ 설정은 추후 언제든 변경 가능

프로젝트 화면 좌측 메뉴에서 ‘Realtime Database’로 진입한다.

‘데이터베이스 만들기‘ 버튼을 클릭한다.

22 | 2. 실습 ― 5) Firebase

# 데이터베이스 만들기

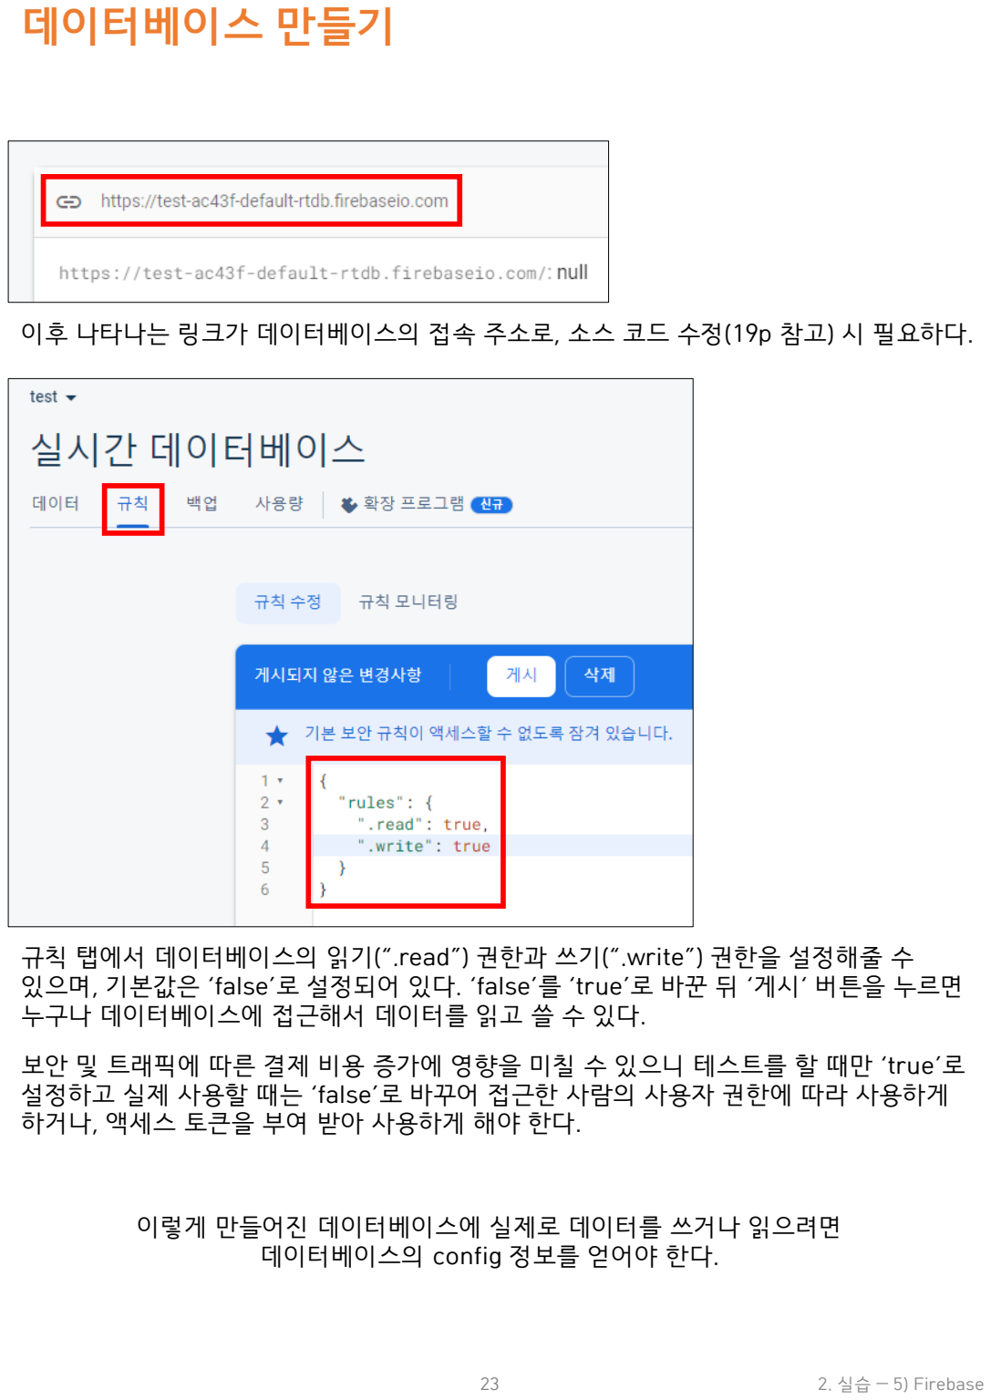
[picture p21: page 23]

이후 나타나는 링크가 데이터베이스의 접속 주소로, 소스 코드 수정(19p 참고) 시 필요하다.

규칙 탭에서 데이터베이스의 읽기(“.read”) 권한과 쓰기(“.write”) 권한을 설정해줄 수 있으며, 기본값은 ‘false’로 설정되어 있다. ‘false’를 ‘true’로 바꾼 뒤 ‘게시‘ 버튼을 누르면 누구나 데이터베이스에 접근해서 데이터를 읽고 쓸 수 있다.

보안 및 트래픽에 따른 결제 비용 증가에 영향을 미칠 수 있으니 테스트를 할 때만 ‘true’로 설정하고 실제 사용할 때는 ‘false’로 바꾸어 접근한 사람의 사용자 권한에 따라 사용하게 하거나, 액세스 토큰을 부여 받아 사용하게 해야 한다.

이렇게 만들어진 데이터베이스에 실제로 데이터를 쓰거나 읽으려면 데이터베이스의 config 정보를 얻어야 한다.

23 | 2. 실습 ― 5) Firebase

# 데이터베이스 config 정보 얻기

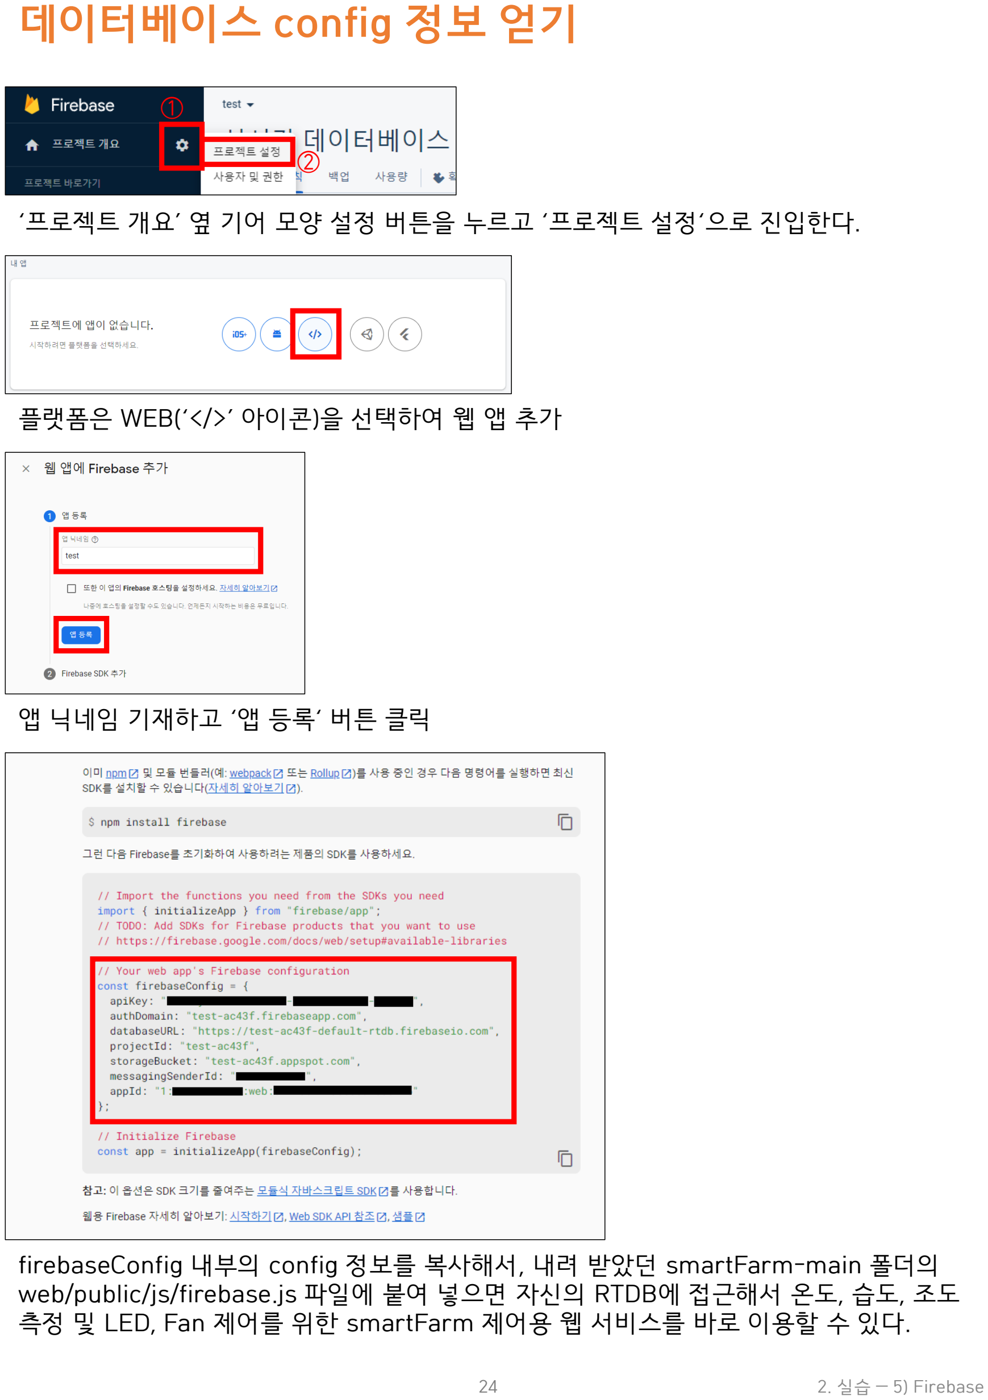
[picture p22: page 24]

‘프로젝트 개요’ 옆 기어 모양 설정 버튼을 누르고 ‘프로젝트 설정‘으로 진입한다.

플랫폼은 WEB(‘</>’ 아이콘)을 선택하여 웹 앱 추가

앱 닉네임 기재하고 ‘앱 등록‘ 버튼 클릭

firebaseConfig 내부의 config 정보를 복사해서, 내려 받았던 smartFarm-main 폴더의 web/public/js/firebase.js 파일에 붙여 넣으면 자신의 RTDB에 접근해서 온도, 습도, 조도 측정 및 LED, Fan 제어를 위한 smartFarm 제어용 웹 서비스를 바로 이용할 수 있다.

24 | 2. 실습 ― 5) Firebase

①

②

# 컴퓨터에서 직접 웹페이지 서비스하기

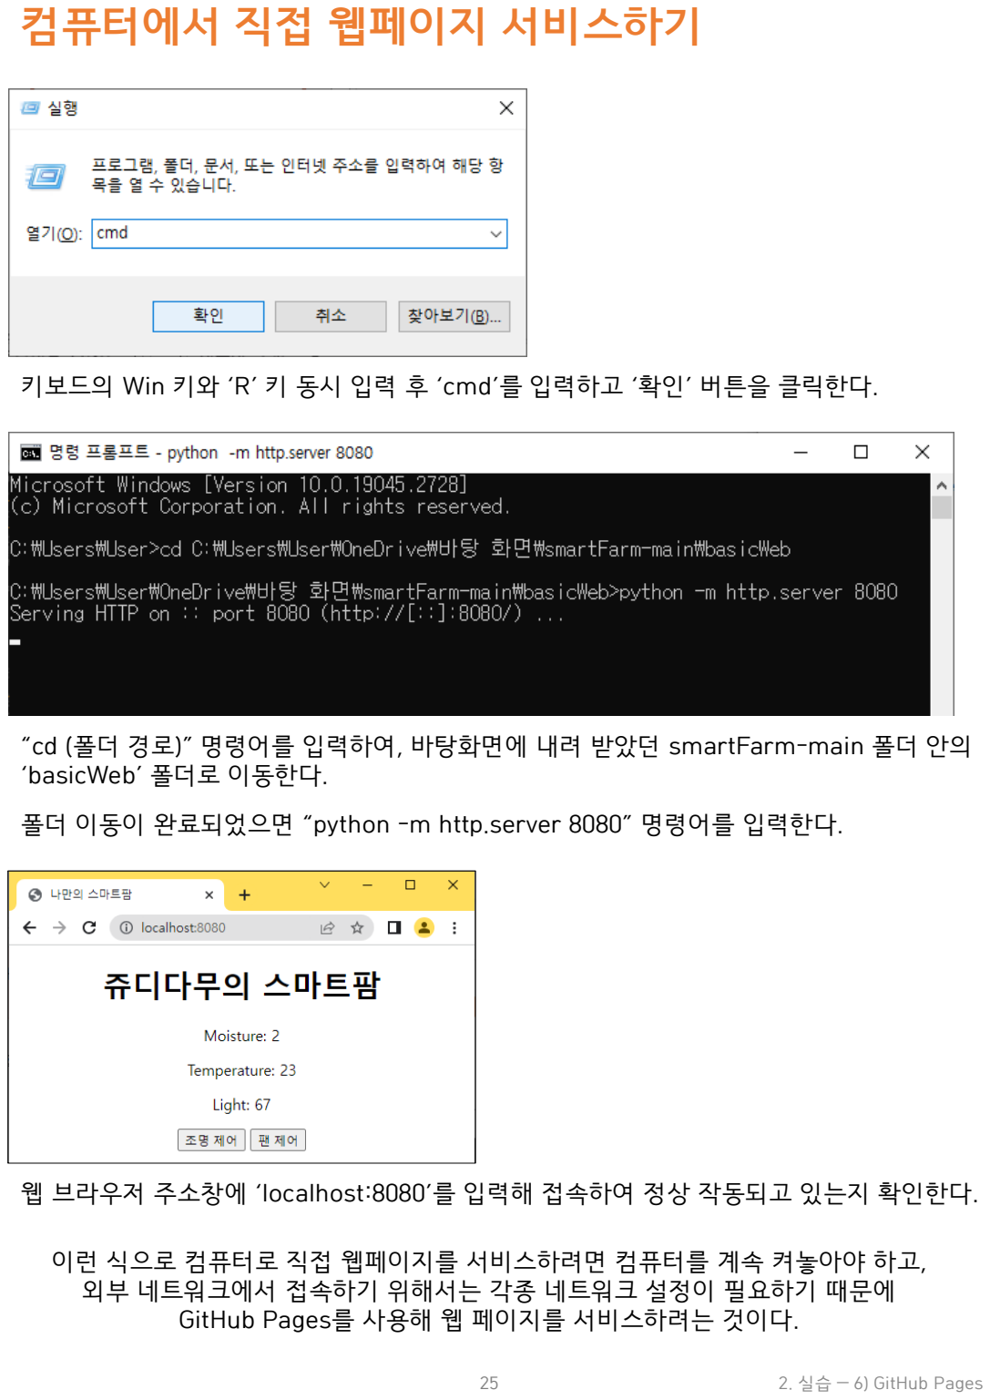
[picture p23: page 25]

“cd (폴더 경로)” 명령어를 입력하여, 바탕화면에 내려 받았던 smartFarm-main 폴더 안의 ‘basicWeb’ 폴더로 이동한다.

폴더 이동이 완료되었으면 “python -m http.server 8080” 명령어를 입력한다.

웹 브라우저 주소창에 ‘localhost:8080’를 입력해 접속하여 정상 작동되고 있는지 확인한다.

25 | 2. 실습 ― 6) GitHub Pages

이런 식으로 컴퓨터로 직접 웹페이지를 서비스하려면 컴퓨터를 계속 켜놓아야 하고, 외부 네트워크에서 접속하기 위해서는 각종 네트워크 설정이 필요하기 때문에 GitHub Pages를 사용해 웹 페이지를 서비스하려는 것이다.

키보드의 Win 키와 ‘R’ 키 동시 입력 후 ‘cmd’를 입력하고 ‘확인’ 버튼을 클릭한다.

# GitHub Repository 만들기

GitHub Pages는 HTML, CSS, JavaScript로 구현되는 정적 웹페이지를 호스트하는 서비스를 무료로 제공하고 있다.

https://github.com

GitHub 사이트에 접속하여 회원가입(Sign up)을 진행한다.

GitHub 메인 페이지 우측 상단의 ‘+’ 버튼을 클릭하고 ‘New repository’ 버튼을 클릭한다.

Repository name을 입력하고, 기본 해제 되어 있는 ‘Add a README file’ 체크박스는 체크하여 ‘Create repository’ 버튼을 클릭한다.

26 | 2. 실습 ― 6) GitHub Pages

①

②

③

①

②

# GitHub Pages 사용 설정하기

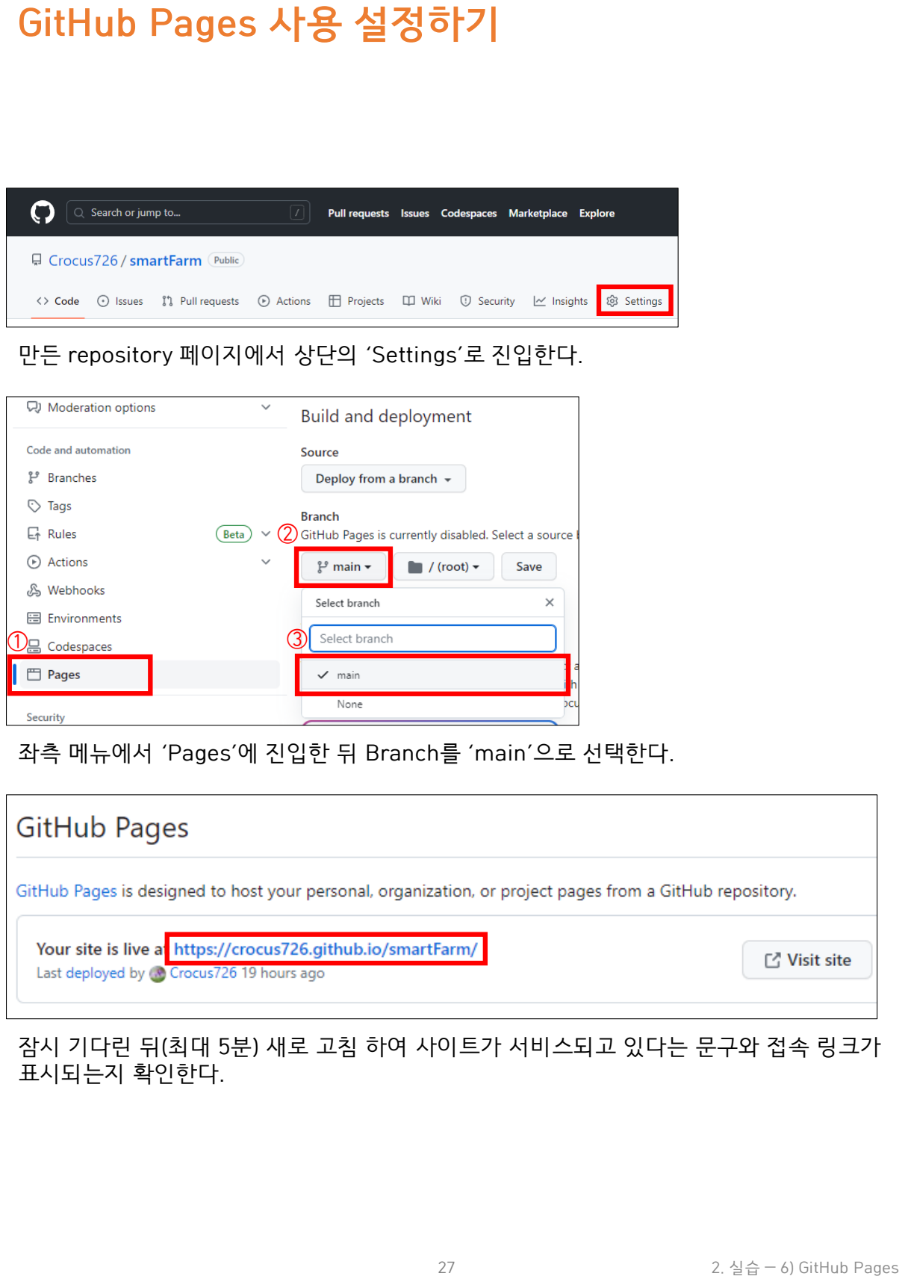
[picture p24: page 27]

만든 repository 페이지에서 상단의 ‘Settings’로 진입한다.

좌측 메뉴에서 ‘Pages’에 진입한 뒤 Branch를 ‘main’으로 선택한다.

잠시 기다린 뒤(최대 5분) 새로 고침 하여 사이트가 서비스되고 있다는 문구와 접속 링크가 표시되는지 확인한다.

27 | 2. 실습 ― 6) GitHub Pages

①

②

③

# GitHub Pages 사용 설정하기

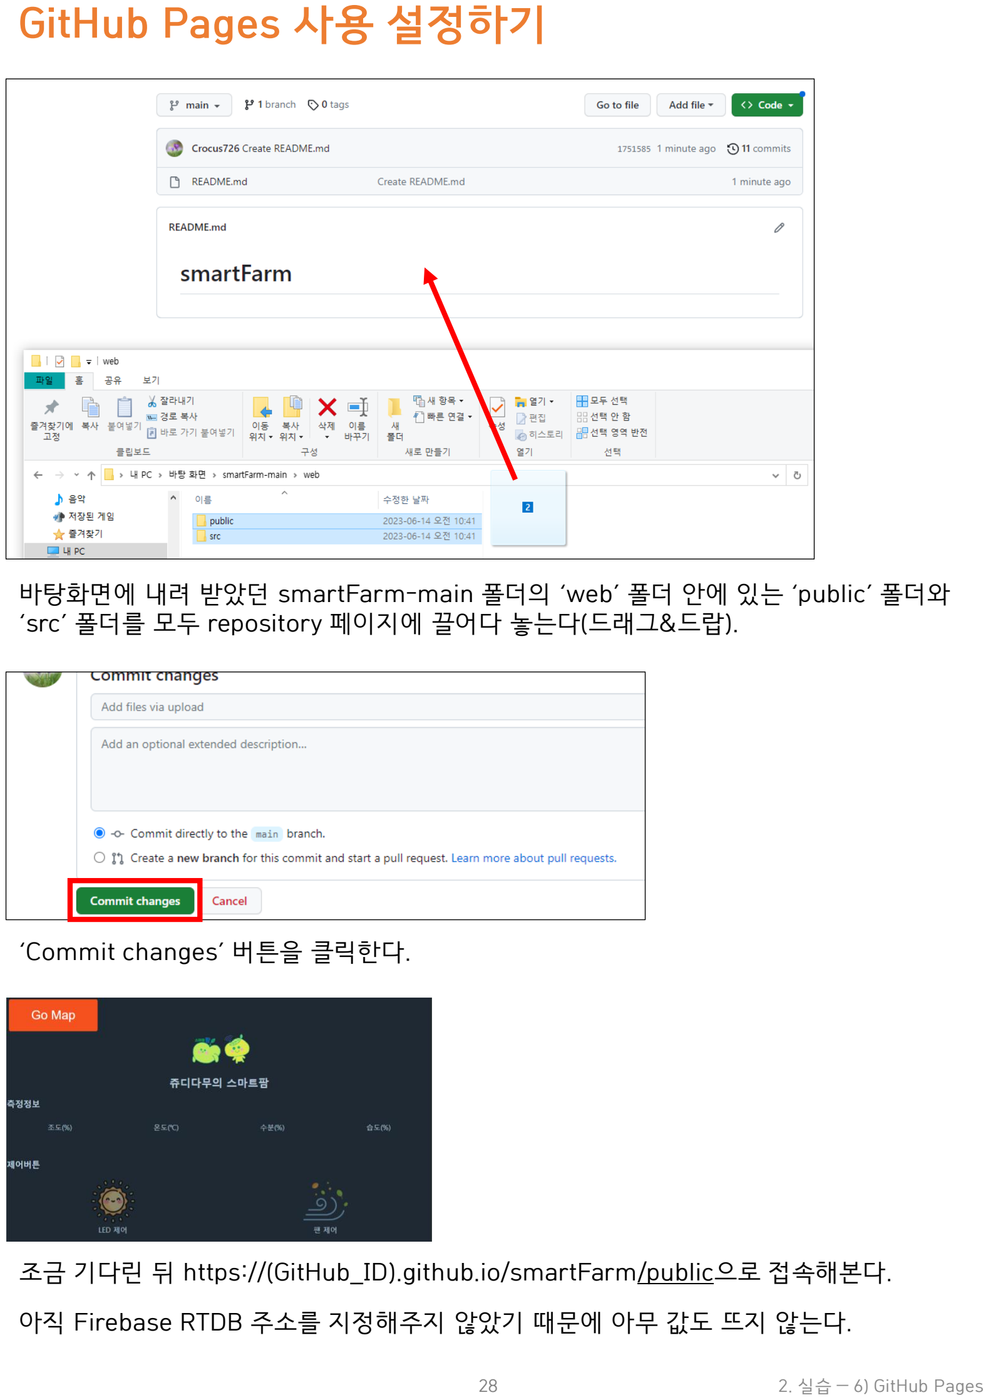
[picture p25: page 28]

바탕화면에 내려 받았던 smartFarm-main 폴더의 ‘web’ 폴더 안에 있는 ‘public’ 폴더와 ‘src’ 폴더를 모두 repository 페이지에 끌어다 놓는다(드래그&드랍).

조금 기다린 뒤 https://(GitHub_ID).github.io/smartFarm/public으로 접속해본다.

아직 Firebase RTDB 주소를 지정해주지 않았기 때문에 아무 값도 뜨지 않는다.

28 | 2. 실습 ― 6) GitHub Pages

‘Commit changes’ 버튼을 클릭한다.

# GitHub Pages 사용 설정하기

repository 페이지에서 ‘public/js’ 폴더로 이동해 ‘firebase.js’ 파일을 클릭한다.

코드 우측 상단의 연필 모양 ‘Edit this file’ 버튼을 클릭한다.

12~18번째 줄의 Firebase RTDB config 정보를 자신의 RTDB config 정보(24p 참고)로 수정하고 ‘Commit changes... → Commit changes’를 클릭한다.

29 | 2. 실습 ― 6) GitHub Pages

①

②

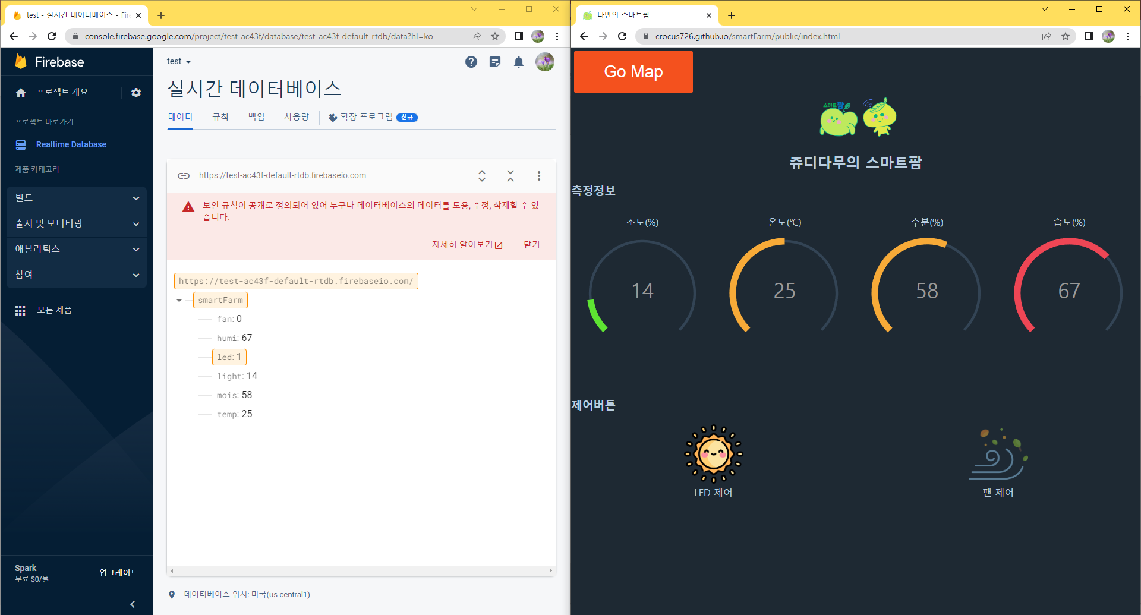
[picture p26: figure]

30 | 2. 실습 ― 7) 최종 작동 확인

다음의 사항을 확인하여 본다.

① 라즈베리 파이 피코가 측정한 값이 Firebase RTDB에 제대로 업로드 되는지
② Firebase RTDB에 저장된 값과 웹페이지에 표시되는 값이 동일한지
③ 식물 생장 LED와 쿨링 팬을 제어할 때 Firebase RTDB에 저장된 값이 제대로 바뀌고 라즈베리 파이 피코가 LED와 팬을 제대로 제어하는지

# 최종 작동 확인

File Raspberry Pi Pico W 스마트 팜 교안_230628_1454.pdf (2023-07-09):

# 라즈베리 파이 피코 W를 활용한 IoT 스마트 팜 만들기

목차

1. 이론

### 1) 라즈베리 파이 피코(Raspberry Pi Pico)

### (1) 라즈베리 파이 피코 알아보기

### (2) 라즈베리 파이 피코 W

### (3) 사용 시 참고할 문서 및 예제

### 2) IoT 스마트 팜

### (1) 스마트 팜 작동 구조

### (2) 스마트 팜 부품 구성도

### (3) 스마트 팜에 사용되는 부품

2. 실습

### 1) 파일 내려 받기

### (1) 스마트 팜 소스 코드 내려 받기

### (2) 라즈베리 파이 피코 W 펌웨어 설치

### 2) 통합개발환경(IDE) Thonny

### (1) Thonny 설치

### (2) Thonny 인터프리터 설정

### (3) Thonny 화면 구성

### (4) Thonny 사용 방법

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
### 3) 회로 구성

### (1) 확장 쉴드 결합

### (2) 센서 모듈 연결

### (3) 식물 생장 LED, OLED 연결

### (4) 모터 연결

### (5) 전원 연결

### 4) 소스 코드

### (1) 사용되는 소스 코드

### (2) 소스 코드 수정

### (3) 소스 코드 업로드

### 5) Firebase

### (1) Firebase 프로젝트 만들기

### (2) 데이터베이스 만들기

### (3) 데이터베이스 config 정보 얻기

### 6) GitHub Pages

### (1) 컴퓨터에서 직접 웹페이지 서비스하기

### (2) GitHub repository 만들기

### (3) GitHub Pages 사용 설정하기

### 7) 최종 작동 확인

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
# 라즈베리 파이 피코 알아보기


라즈베리 파이 피코는 영국의 라즈베리 파이 재단에서 개발한 RP2040 칩을 탑재해 C언어나 마이크로파이썬(MicroPython) 등의 프로그래밍 언어로 동작하도록 한 가정·산업용 마이크로컨트롤러 보드이다.

* 마이크로컨트롤러: 마이크로프로세서와 입출력 장치를 하나의 칩으로 만들어 정해진 기능을 수행하도록 한 컴퓨터

여러 소프트웨어를 구동하도록 설계된 운영체제(OS)가 들어가는 라즈베리 파이와는 달리, 라즈베리 파이 피코에는 펌웨어가 들어간다. 이 때문에 성능은 상용 PC에 비해 낮으나 단순하고 반복적인 동작을 수행하는 피지컬 컴퓨팅에 최적화되어 있다.

4 | 1. 이론 ― 1) 라즈베리 파이 피코

전원 핀(3V3, GND)으로 센서와 액추에이터에 전원을 공급하고 GPIO(다용도 입출력) 핀으로 센서나 액추에이터와 전기 신호를 주고 받을 수 있다. 프로그래밍 언어로 작성된 소스 코드를 업로드하면 센서의 측정 값을 읽거나 LED 점등, 모터 회전 등의 동작을 수행할 수 있다.


라즈베리 파이 피코 W는 무선 통신이 필요한 IoT 애플리케이션 및 프로젝트를 위해 라즈베리 파이 피코에 2.4 GHz 802.11n 무선 LAN을 탑재한 버전이다. 무선 LAN이 탑재되어 있어 Wi-Fi 연결(2.4 GHz)이 가능하고 인터넷에도 접속하여 세계 어디에서나 라즈베리 파이 피코 W를 통해 제어하도록 할 수도 있다.

라즈베리 파이 피코와는 무선 LAN이 탑재된 것을 제외하고는 마이크로컨트롤러(RP2040), 플래시 메모리 용량 등의 사양이 모두 동일하고 GPIO 핀의 개수와 구성도 똑같다. 따라서 라즈베리 파이 피코에서 작동하는 소스 코드를 피코 W에 그대로 붙여 넣고 Wi-Fi를 사용하는 기능을 추가할 수도 있다.

# 라즈베리 파이 피코 W

5 | 1. 이론 ― 1) 라즈베리 파이 피코


https://datasheets.raspberrypi.com/picow/pico-w-datasheet.pdf

라즈베리 파이 피코 W의 설계 파일, 기계적 사양, 응용 프로그램 정보 등을 적은 데이터시트

https://www.raspberrypi.com/documentation/microcontrollers/raspberry-pi-pico.html

라즈베리 파이 피코와 피코 W의 사용 방법을 설명하는 라즈베리 파이 재단의 공식 문서


https://make.e4ds.com/contest/board_view.asp?idx=653&ctidx=8

라즈베리 파이 피코 W로 각종 센서와 액추에이터를 제어하는 방법을 설명하는 문서

# 사용 시 참고할 문서 및 예제

6 | 1. 이론 ― 1) 라즈베리 파이 피코

# 스마트 팜 작동 구조

데이터; 전원 & 데이터; 라즈베리 파이 피코 W; 드라이버; 식물 생장 LED; 18650 배터리; TP4056 충방전 모듈; 태양광 전지 판; OLED; 온습도 센서 모듈; CdS 조도 센서 모듈; 1. 이론 ― 2) IoT 스마트 팜

데이터베이스(Realtime Database,
RTDB)에 데이터를 저장

데이터베이스로부터 온도, 습도, 수분, 조도 값을 받아오고,

식물 생장 LED, 쿨링 팬 제어 명령을 전송함

온도, 습도, 수분, 조도를 측정해 데이터베이스로 전송하고,

식물 생장 LED, 쿨링 팬 제어 명령을 받음

스마트 팜 부품 구성도

라즈베리 파이 피코 W

피코 확장 쉴드

OLED(I2C 타입)

식물 생장 LED

Python 프로그램을 통해 각종 센서와 액추에이터를 GPIO 핀에 연결하여 제어하고 인터넷에 연결하여 데이터베이스와 데이터를 주고 받는다.

라즈베리 파이 피코를 결합해 GPIO 핀을 확장한다.

I2C 통신으로 피코 W로부터 데이터를 받아 화면에 표시한다.

실내에서 식물을 재배할 때 부족한 햇빛을 대체한다.

토양 수분 센서 모듈

CdS 조도 센서 모듈

온습도 센서 모듈(AHT10)

흙에 꽂아 저항 값을 측정해 흙에 포함된 수분이 얼마나 많은지를 측정한다.

광자 양이 많으면 저항 값이 낮아지고 광자 양이 적으면 저항 값이 높아지는 황화 카드뮴(CdS)의 특성을 이용해 조도를 측정한다.

측정된 온도와 습도 값을 I2C 통신을 통해 전송한다.

# 스마트 팜에 사용되는 부품

8 | 1. 이론 ― 2) IoT 스마트 팜

# 스마트 팜에 사용되는 부품

2ch 모터 드라이버

워터 펌프 모터

쿨링 팬

날개를 회전시켜 액체에 회전력을 주어
액체의 위치를 바꾼다.

모터의 회전 방향, 회전 속도 등을 입력 받아 모터를 제어한다.

날개를 회전시켜 바람을 일으킨다.

충방전 모듈(TP4056)

18650 배터리(+홀더)


태양광 전지 판

반도체의 광전효과를 이용해 태양빛을 전기 에너지로 변환한다.

리튬 이온 배터리로, 전기 에너지를 모아 두었다가 필요할 때 출력한다.

USB 포트를 통해 리튬 이온 배터리를 충전하고 리튬 이온 배터리의 전기 에너지를 외부에 연결된 장치로 출력한다.

9 | 1. 이론 ― 2) IoT 스마트 팜

# 스마트 팜 소스 코드 내려 받기


https://github.com/mtinet/smartFarm

‘Code’ 버튼을 클릭하고 ‘Download ZIP’ 버튼을 클릭해 압축 파일을 내려 받는다.

파일을 압축 해제하여 smartFarm-main 폴더를 바탕화면에 놓는다.

10 | 2. 실습 ― 1) 파일 내려 받기

②

①

https://micropython.org/download/rp2-pico-w/

라즈베리 파이 피코 W에 탑재되는 펌웨어(.uf2 파일)를 내려 받는다.


보드의 bootsel 버튼을 누른 채로 USB 케이블로 컴퓨터와 연결한다.


피코 W 폴더(내 PC → ‘RPI-RP2’ 드라이브)에 펌웨어 파일을 붙여 넣는다.

# 라즈베리 파이 피코 W 펌웨어 설치

11 | 2. 실습 ― 1) 파일 내려 받기

라즈베리 파이 피코에는 프로그래밍 언어로 작성된 소스 코드를 업로드해야 한다. Thonny는 마이크로파이썬으로 소스 코드를 작성하고 라즈베리 파이 피코로 실행 및 업로드할 수 있도록 하는 파이썬 용 통합 개발 환경(IDE)이다.

Thonny는 라즈베리 파이 피코 개발을 위한 마이크로파이썬 인터프리터와 모듈이 사전에 설치 되어 있어 Thonny 하나만 설치하면 피코 W 사용에 필요한 환경을 한 번에 구축할 수 있다.

# Thonny 설치

https://thonny.org/

Thonny의 최신 버전을 내려 받아 설치한다.

12 | 2. 실습 ― 2) 통합개발환경(IDE) Thonny

# Thonny 인터프리터 설정


Thonny를 켜고 ‘Run → Configure interpreter...’로 진입한다.

드롭 다운 메뉴에서 ‘MicroPython (Raspberry Pi Pico)’를 선택한다.

피코 W가 연결되어 있는 포트를 선택하고 ‘OK’ 버튼을 클릭한다.

인터프리터 설정을 마치면 마이크로파이썬으로 소스 코드를 작성하고 피코 W에 업로드하거나 곧바로 실행 명령을 내려 동작을 수행하도록 할 수 있다.

13 | 2. 실습 ― 2) 통합개발환경(IDE) Thonny

①

②

①

②

①
②

③

# Thonny 화면 구성 & 사용 방법


14 | 2. 실습 ― 2) 통합개발환경(IDE) Thonny

소스 코드 에디터에 소스 코드를 작성하고, 상단 메뉴에서 초록색 재생 버튼과 정지 버튼을 눌러서 라즈베리 파이 피코가 소스 코드 실행을 시작하거나 멈추게 할 수 있다.

라즈베리 파이 피코 내에서 소스 코드가 실행되면 피코의 파이썬 펌웨어가 연산한 결과를 파이썬 상태 확인용 콘솔에 보여주게 된다.

Thonny를 통해 소스 코드를 실행하지 않고, 라즈베리 파이 피코에 전원이 입력되면 소스 코드가 자동으로 실행되도록 하려면 상단 메뉴의 ‘File → Save as... → Raspberry Pi Pico’로 진입해 피코 내부 저장 공간에 ‘main.py’라는 이름으로 소스 코드를 저장해야 한다(20p 참고).

내 컴퓨터에서
탐색 중인
폴더와 파일

라즈베리 파이 피코
내부 저장 공간

소스 코드
에디터

파이썬 상태
확인용 콘솔

메뉴

# 회로 구성 ― 확장 쉴드 결합

① 피코 W 확장 쉴드에 피코 W를 결합
※ 쉴드 윗면 프린팅을 참고하여 피코 W의 방향 확인

② 온습도 센서 모듈의 SDA를 피코 W의 GP14에, 온습도 센서 모듈의 SCL을 피코 W의 GP15에, 온습도 센서 모듈의 GND를 피코 W의 GND에, 온습도 센서 모듈의 VIN을 피코 W의 3V3에 연결

③ 토양 수분 센서 모듈의 A0을 피코 W의 GP26(A0)에, 토양 수분 센서 모듈의 GND를 피코 W의 GND에, 토양 수분 센서 모듈의 VCC를 피코 W의 3V3에 연결

④ CdS 조도 센서 모듈의 A0을 피코 W의 GP27(A1)에, CdS 조도 센서 모듈의 GND를 피코 W의 GND에, CdS 조도 센서 모듈의 VCC를 피코 W의 3V3에 연결

# 회로 구성 ― 센서 모듈 연결

15 | 2. 실습 ― 3) 회로 구성

# 회로 구성 ― 식물 생장 LED, OLED 연결


⑤ 식물 생장 LED의 (+)를 피코 W의 3V3에, 식물 생장 LED의 (-)를 피코 W의 GND에 연결

⑥ OLED의 SDA를 피코 W의 GP16에,
OLED의 SCK를 피코 W의 GP17에,
OLED의 VDD를 피코 W의 3V3에,
OLED의 GND를 피코 W의 GND에 연결

⑦ 모터 드라이버의 A-IB를 피코 W의 GP9에, 모터 드라이버의 A-IA를 피코 W의 GND에, 모터 드라이버의 VCC를 피코 W의 USB에,
모터 드라이버의 GND를 피코 W의 GND에,
모터 드라이버의 B-IB를 피코 W의 GND에, 모터 드라이버의 B-IA를 피코 W의 GP5에 연결

⑧ 워터 펌프 모터를 모터 드라이버의 A 채널에, 쿨링 팬을 모터 드라이버의 B 채널에 연결

# 회로 구성 ― 모터 연결

16 | 2. 실습 ― 3) 회로 구성


⑨ 충방전 모듈의 OUT-를 피코 W의 GND에,
충방전 모듈의 OUT+를 피코 W의 VUSB에 연결

⑩ 18650 배터리 홀더의 (+)를 충방전 모듈의 B+에, 18650 배터리 홀더의 (-)를 충방전 모듈의 B-에 연결

⑪ 태양광 전지 판의 (+)를 충방전 모듈의 (+)에,
태양광 전지 판의 (-)를 충방전 모듈의 (-)에 연결

# 회로 구성 ― 전원 연결

17 | 2. 실습 ― 3) 회로 구성


바탕화면에 내려 받았던(10p 참고) smartFarm-main 폴더의 ‘pico’ 폴더에 진입한다.

- base.py: 데이터베이스(Firebase RTDB)에 데이터를 랜덤 값으로 업로드하는 코드
- boot.py: 전원을 켰을 때 가장 먼저 실행되는 보드 설정 코드
- main(non-OLED).py: OLED를 사용하지 않는 스마트 팜의 메인 실행 코드
- main.py: OLED를 사용하는 스마트 팜의 메인 실행 코드
- ssd1306.py: OLED를 사용하기 위한 모듈 파일(OLED 사용 시 같이 업로드)

OLED를 사용하는 경우: boot.py, main.py, ssd1306.py가 필요
OLED를 사용하지 않는 경우: boot.py, main(non-OLED).py가 필요

파일을 열 때는 파일을 우클릭한 후 ‘연결 프로그램(H) → Thonny’를 선택한다.

# 사용되는 소스 코드

18 | 2. 실습 ― 4) 소스 코드

base.py, main(non-OLED).py, main.py가 보드에 업로드 되면, 피코 W에 전원이 입력되었을 때 자동으로 소스 코드가 실행된다. 그 전에 피코 W가 연결할 Wi-Fi 공유기의 SSID(이름)와 패스워드를 수정해야 하며, Firebase RTDB의 주소도 수정해야 한다.
※ Firebase RTDB의 주소: 23p ‘데이터베이스 만들기‘에서 확인

# 소스 코드 수정


19 | 2. 실습 ― 4) 소스 코드
- base.py: 19, 29번째 줄 수정
- main(non-OLED).py: 14~15, 18번째 줄 수정
- main.py: 15~16, 24번째 줄 수정

파이썬 파일(.py)을 연 상태에서 ‘File → Save as...’로 진입한다.

‘Raspberry Pi Pico’를 선택한다.


피코 W에 업로드 할 각각의 파일에 대하여 위 과정을 수행한다.
OLED를 사용하는 경우: boot.py, main.py, ssd1306.py가 필요
OLED를 사용하지 않는 경우: boot.py, main(non-OLED).py가 필요

피코 W에 업로드된 파이썬 소스 코드는 피코 W에 전원이 입력됐을 때 자동으로 실행된다.

File name에 파일 이름을 확장자명(.py)까지 적고 ‘OK’ 버튼을 클릭한다.
※ main(non-OLED).py 파일은 저장할 때 파일 이름을 ‘main.py’로 저장하여야 함

20

# 소스 코드 업로드

2. 실습 ― 4) 소스 코드

# Firebase 프로젝트 만들기


https://firebase.google.com/

구글 계정으로 로그인한 뒤 우측 상단 ‘콘솔로 이동’ 버튼을 클릭한다.

‘프로젝트 만들기‘ 버튼을 클릭한다.

프로젝트 이름을 지정하고 체크박스에 모두 체크한 뒤 ‘계속‘ 버튼을 클릭한다.

Google 애널리틱스 사용은 해제하고 ‘프로젝트 만들기‘ 버튼을 클릭한다.

21 | 2. 실습 ― 5) Firebase

# 데이터베이스 만들기

데이터베이스의 물리적 위치를 선택하고 ‘다음‘ 버튼을 클릭한다.

‘잠금 모드로 시작’으로 놔두고 ‘사용 설정’ 버튼을 클릭한다.
※ 설정은 추후 언제든 변경 가능

프로젝트 화면 좌측 메뉴에서 ‘Realtime Database’로 진입한다.

‘데이터베이스 만들기‘ 버튼을 클릭한다.

22 | 2. 실습 ― 5) Firebase

# 데이터베이스 만들기


이후 나타나는 링크가 데이터베이스의 접속 주소로, 소스 코드 수정(19p 참고) 시 필요하다.

규칙 탭에서 데이터베이스의 읽기(“.read”) 권한과 쓰기(“.write”) 권한을 설정해줄 수 있으며, 기본값은 ‘false’로 설정되어 있다. ‘false’를 ‘true’로 바꾼 뒤 ‘게시‘ 버튼을 누르면 누구나 데이터베이스에 접근해서 데이터를 읽고 쓸 수 있다.

보안 및 트래픽에 따른 결제 비용 증가에 영향을 미칠 수 있으니 테스트를 할 때만 ‘true’로 설정하고 실제 사용할 때는 ‘false’로 바꾸어 접근한 사람의 사용자 권한에 따라 사용하게 하거나, 액세스 토큰을 부여 받아 사용하게 해야 한다.

이렇게 만들어진 데이터베이스에 실제로 데이터를 쓰거나 읽으려면 데이터베이스의 config 정보를 얻어야 한다.

23 | 2. 실습 ― 5) Firebase

# 데이터베이스 config 정보 얻기


‘프로젝트 개요’ 옆 기어 모양 설정 버튼을 누르고 ‘프로젝트 설정‘으로 진입한다.

플랫폼은 WEB(‘</>’ 아이콘)을 선택하여 웹 앱 추가

앱 닉네임 기재하고 ‘앱 등록‘ 버튼 클릭

firebaseConfig 내부의 config 정보를 복사해서, 내려 받았던 smartFarm-main 폴더의 web/public/js/firebase.js 파일에 붙여 넣으면 자신의 RTDB에 접근해서 온도, 습도, 조도 측정 및 LED, Fan 제어를 위한 smartFarm 제어용 웹 서비스를 바로 이용할 수 있다.

24 | 2. 실습 ― 5) Firebase

①

②

# 컴퓨터에서 직접 웹페이지 서비스하기


“cd (폴더 경로)” 명령어를 입력하여, 바탕화면에 내려 받았던 smartFarm-main 폴더 안의 ‘basicWeb’ 폴더로 이동한다.

폴더 이동이 완료되었으면 “python -m http.server 8080” 명령어를 입력한다.

웹 브라우저 주소창에 ‘localhost:8080’를 입력해 접속하여 정상 작동되고 있는지 확인한다.

25 | 2. 실습 ― 6) GitHub Pages

이런 식으로 컴퓨터로 직접 웹페이지를 서비스하려면 컴퓨터를 계속 켜놓아야 하고, 외부 네트워크에서 접속하기 위해서는 각종 네트워크 설정이 필요하기 때문에 GitHub Pages를 사용해 웹 페이지를 서비스하려는 것이다.

키보드의 Win 키와 ‘R’ 키 동시 입력 후 ‘cmd’를 입력하고 ‘확인’ 버튼을 클릭한다.

# GitHub Repository 만들기

GitHub Pages는 HTML, CSS, JavaScript로 구현되는 정적 웹페이지를 호스트하는 서비스를 무료로 제공하고 있다.

https://github.com

GitHub 사이트에 접속하여 회원가입(Sign up)을 진행한다.

GitHub 메인 페이지 우측 상단의 ‘+’ 버튼을 클릭하고 ‘New repository’ 버튼을 클릭한다.

Repository name을 입력하고, 기본 해제 되어 있는 ‘Add a README file’ 체크박스는 체크하여 ‘Create repository’ 버튼을 클릭한다.

26 | 2. 실습 ― 6) GitHub Pages

①

②

③

①

②

# GitHub Pages 사용 설정하기


만든 repository 페이지에서 상단의 ‘Settings’로 진입한다.

좌측 메뉴에서 ‘Pages’에 진입한 뒤 Branch를 ‘main’으로 선택한다.

잠시 기다린 뒤(최대 5분) 새로 고침 하여 사이트가 서비스되고 있다는 문구와 접속 링크가 표시되는지 확인한다.

27 | 2. 실습 ― 6) GitHub Pages

①

②

③

# GitHub Pages 사용 설정하기


바탕화면에 내려 받았던 smartFarm-main 폴더의 ‘web’ 폴더 안에 있는 ‘public’ 폴더와 ‘src’ 폴더를 모두 repository 페이지에 끌어다 놓는다(드래그&드랍).

조금 기다린 뒤 https://(GitHub_ID).github.io/smartFarm/public으로 접속해본다.

아직 Firebase RTDB 주소를 지정해주지 않았기 때문에 아무 값도 뜨지 않는다.

28 | 2. 실습 ― 6) GitHub Pages

‘Commit changes’ 버튼을 클릭한다.

# GitHub Pages 사용 설정하기

repository 페이지에서 ‘public/js’ 폴더로 이동해 ‘firebase.js’ 파일을 클릭한다.

코드 우측 상단의 연필 모양 ‘Edit this file’ 버튼을 클릭한다.

12~18번째 줄의 Firebase RTDB config 정보를 자신의 RTDB config 정보(24p 참고)로 수정하고 ‘Commit changes... → Commit changes’를 클릭한다.

29 | 2. 실습 ― 6) GitHub Pages

①

②


30 | 2. 실습 ― 7) 최종 작동 확인

다음의 사항을 확인하여 본다.

① 라즈베리 파이 피코가 측정한 값이 Firebase RTDB에 제대로 업로드 되는지
② Firebase RTDB에 저장된 값과 웹페이지에 표시되는 값이 동일한지
③ 식물 생장 LED와 쿨링 팬을 제어할 때 Firebase RTDB에 저장된 값이 제대로 바뀌고 라즈베리 파이 피코가 LED와 팬을 제대로 제어하는지

# 최종 작동 확인

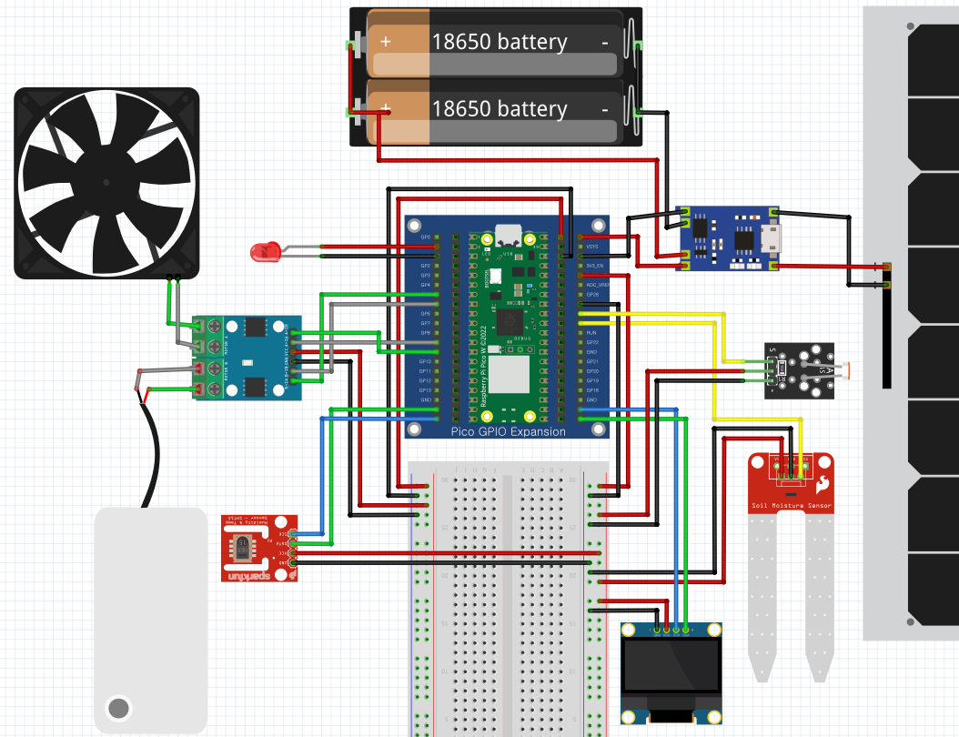
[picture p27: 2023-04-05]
0. circuit/circuit.png

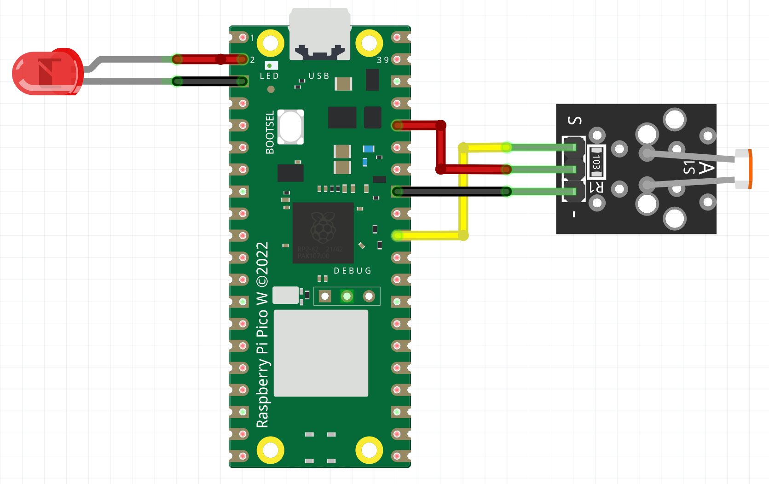
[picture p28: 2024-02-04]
0. circuit/CdSLED.png

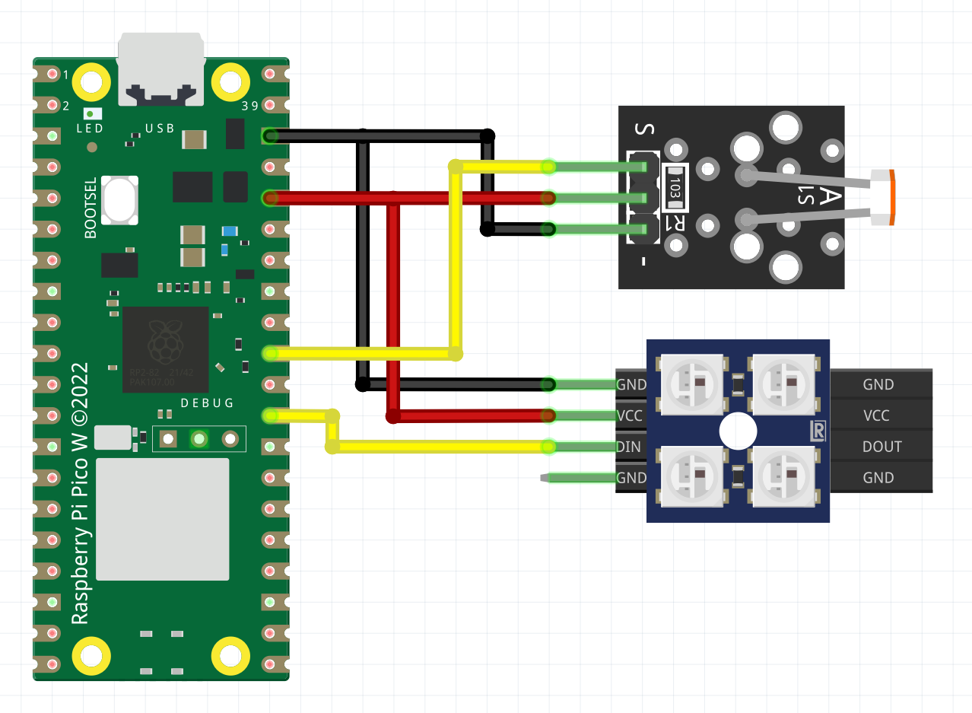
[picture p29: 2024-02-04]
0. circuit/CdSNeopixel.png

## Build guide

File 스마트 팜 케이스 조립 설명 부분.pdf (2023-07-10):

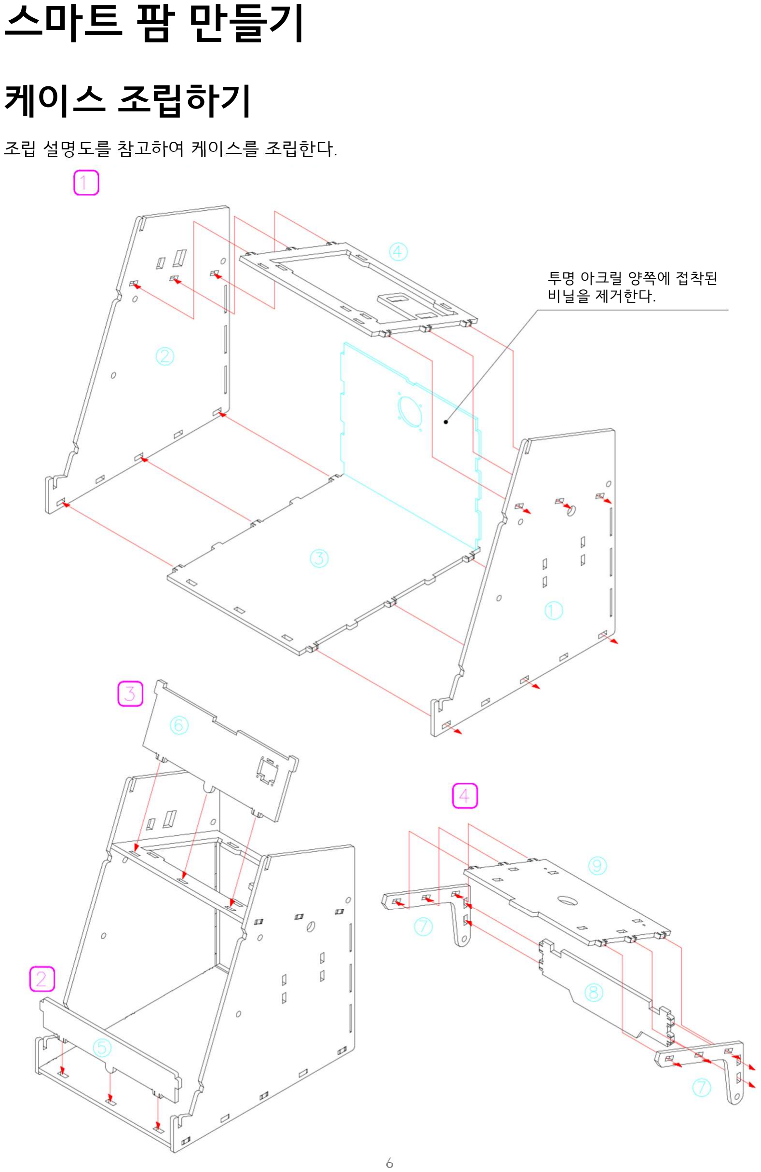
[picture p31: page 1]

6

스마트 팜 만들기

케이스 조립하기

조립 설명도를 참고하여 케이스를 조립한다.

투명 아크릴 양쪽에 접착된
비닐을 제거한다.

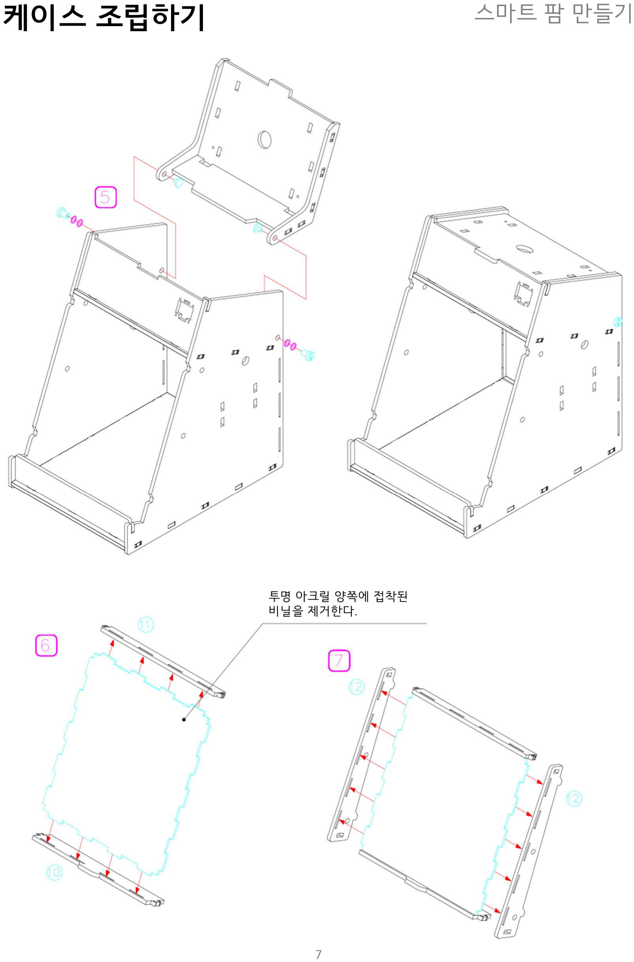
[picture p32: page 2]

7

케이스 조립하기 | 스마트 팜 만들기

투명 아크릴 양쪽에 접착된
비닐을 제거한다.

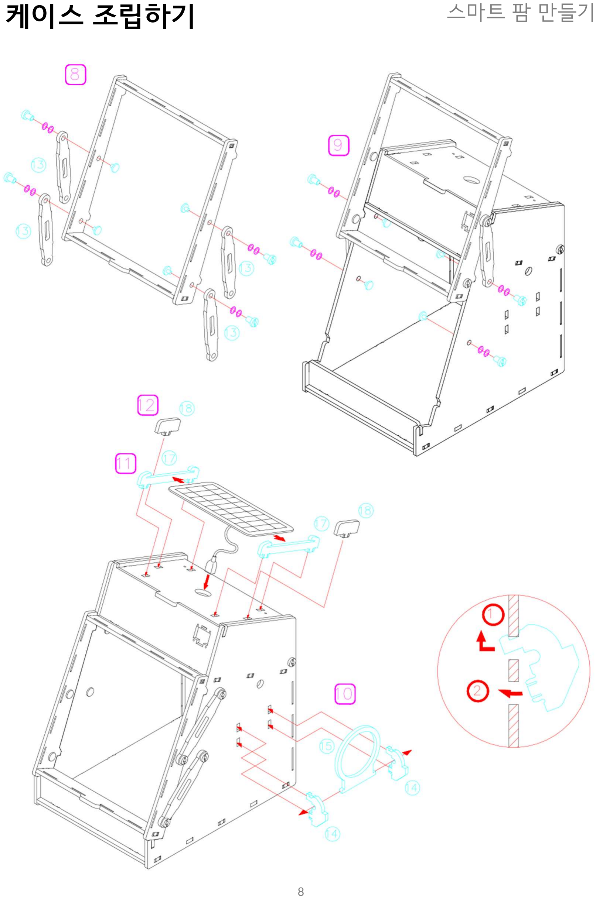
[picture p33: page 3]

8

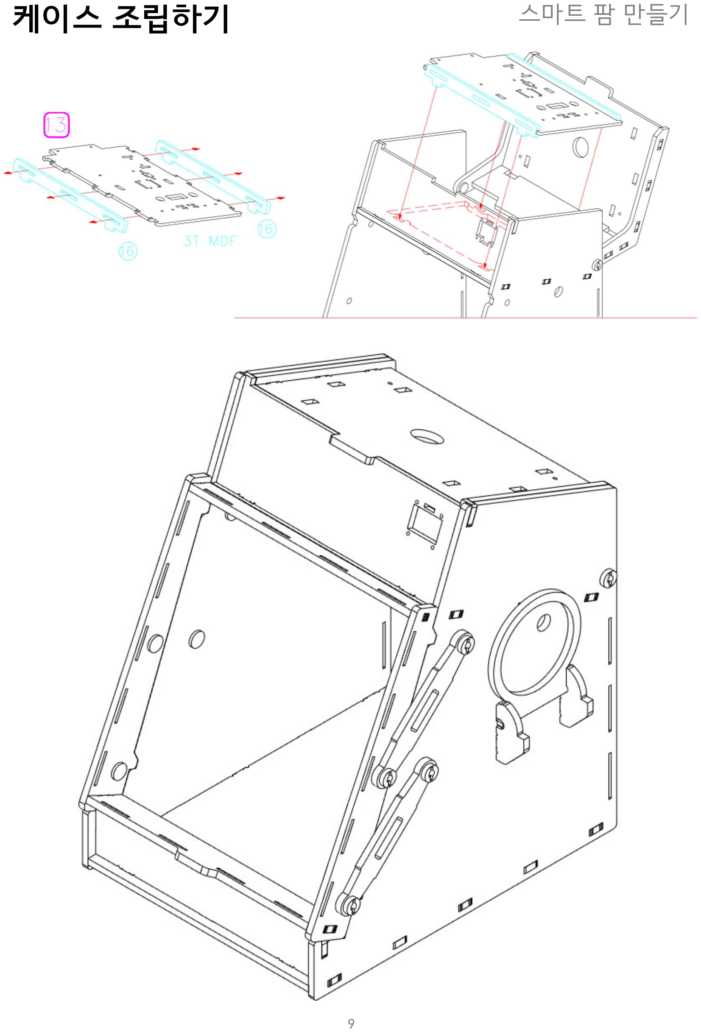
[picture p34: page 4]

9

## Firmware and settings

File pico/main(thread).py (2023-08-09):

# This code was written by Juhyun Kim. 
from machine import Pin, I2C, ADC, PWM
import _thread
import network
import time
import urequests
import random
from ssd1306 import SSD1306_I2C
import framebuf
import ahtx0
from timezoneChange import timeOfSeoul

# 이메일, 위도, 경도 표시하기(자신의 스마트팜 위치를 검색해서 넣어주세요.)
SSID = "U+Net454C"         # 공유기의 SSID를 따옴표 안에 넣으세요.
password = "DDAE014478"       # 공유기의 password를 따옴표 안에 넣으세요.
nickname = 'mtinet'           # 닉네임 변수를 자신만의 닉네임으로 수정하세요.
lat = 37.49836                # 위도 변수를 자신의 위도 좌표로 수정하세요.
long = 126.9253               # 경도 변수를 자신의 경도 좌표로 수정하세요.
moistureStandardValue = 10    # 수분센서 기준값을 설정하세요. 수분 센서 측정값이 이 값보다 작을 때 물 펌프가 동작합니다.
temperatureStandardValue = 20 # 온도센서 기준값을 설정하세요. 온도 센서 측정값이 이 값보다 클 때 팬이 동작합니다. 

# RTDB주소
url = "https://smartfarm-f867f-default-rtdb.firebaseio.com/"
mapUrl = "https://smartfarmlocation-default-rtdb.firebaseio.com/"

# 제어할 핀 번호 설정
led = Pin(1, Pin.OUT) # 생장 LED제어 핀
fan = Pin(5, Pin.OUT) # 팬 제어 핀
pwm = PWM(Pin(9)) # 물 펌프 제어 핀
pwm.freq(1000)

# 수분, 조도 센서 설정
moisture = ADC(26) # 수분 감지
light = ADC(27) # 조도 감지

# 온도, 습도 센서 설정 
i2cTH = I2C(1, scl=Pin(15), sda=Pin(14), freq=200000) 
sensor = ahtx0.AHT10(i2cTH)
conversion_factor = 3.3 / 65535 # 측정값 보정 계산식

# OLED 기본 설정
WIDTH  = 128                                            # oled display width
HEIGHT = 64                                             # oled display height
i2c = I2C(0, scl=Pin(17), sda=Pin(16), freq=200000)       # Init I2C using pins GP8 & GP9 (default I2C0 pins)
print("I2C Address      : "+hex(i2c.scan()[0]).upper()) # Display device address
print("I2C Configuration: "+str(i2c))                   # Display I2C config
oled = SSD1306_I2C(WIDTH, HEIGHT, i2c)                  # Init oled display

# Raspberry Pi logo as 32x32 bytearray
buffer = bytearray(b"\x00\x00\x00\x00\x00\x00\x00\x00\x00\x00\x00\x00\x00|?\x00\x01\x86@\x80\x01\x01\x80\x80\x01\x11\x88\x80\x01\x05\xa0\x80\x00\x83\xc1\x00\x00C\xe3\x00\x00~\xfc\x00\x00L'\x00\x00\x9c\x11\x00\x00\xbf\xfd\x00\x00\xe1\x87\x00\x01\xc1\x83\x80\x02A\x82@\x02A\x82@\x02\xc1\xc2@\x02\xf6>\xc0\x01\xfc=\x80\x01\x18\x18\x80\x01\x88\x10\x80\x00\x8c!\x00\x00\x87\xf1\x00\x00\x7f\xf6\x00\x008\x1c\x00\x00\x0c \x00\x00\x03\xc0\x00\x00\x00\x00\x00\x00\x00\x00\x00\x00\x00\x00\x00")

# OLED에 출력하기
oled.fill(0)
# 프레임버퍼로 로고 불러오기(이미지 사이즈는  32x32)
fb = framebuf.FrameBuffer(buffer, 32, 32, framebuf.MONO_HLSB)
# 프레임 버퍼에서 OLED 디스플레이로 이미지 옮기기
oled.blit(fb, 96, 0)
# 글자 넣기
oled.text("SmartFarm", 0, 25)
oled.text("  has been", 0, 35)
oled.text("    initialized.", 0, 45)
# 이미지와 글자가 보여지도록 하기
oled.show()

# 와이파이 연결하기
wlan = network.WLAN(network.STA_IF)
wlan.active(True)
if not wlan.isconnected():
    # 와이파이 연결하기
    wlan.connect(SSID, password)  # 12, 13번 줄에 입력한 SSID와 password가 입력됨
    print("Waiting for Wi-Fi connection", end="...")
    print()
    while not wlan.isconnected():
        print(".", end="")
        
else:
    print(wlan.ifconfig())
    print("WiFi is Connected")
    print()
    
# 시간정보 가져오기
updatedTime = timeOfSeoul()
# print(type(updatedTime))
print(updatedTime)

# OLED에 출력하기
oled.fill(0)
# 프레임버퍼로 로고 불러오기(이미지 사이즈는  32x32)
fb = framebuf.FrameBuffer(buffer, 32, 32, framebuf.MONO_HLSB)
# 프레임 버퍼에서 OLED 디스플레이로 이미지 옮기기
oled.blit(fb, 96, 0)
# 글자 넣기
oled.text("WiFi", 0, 20)
oled.text("is Connected", 0, 35)
oled.text(updatedTime, 0, 50)
# 이미지와 글자가 보여지도록 하기
oled.show()
time.sleep(0.5)


# RTDB 초기 세팅이 안되어 있는 경우 초기 세팅하기
myobjInitialize = {
    'led': 0,
    'fan': 0
    }

# RTDB 초기 세팅이 안되어 있는 경우 초기 세팅하기
myobjInitializeGather = {
    '-led-': 0,
    '-fan-': 0
    }

# myobjInitialize를 RTDB로 보내 객체 교체하기, patch는 특정 주소의 데이터가 변경됨
urequests.patch(url+"smartFarm.json", json = myobjInitialize).json()
urequests.patch(mapUrl+"/"+nickname+"/"+"smartFarm.json", json = myobjInitializeGather).json()
print("SmartFarm has been initialized.")
time.sleep(0.5)

# RTDB 위치 정보 초기 세팅하기
myLocation = {
    'lat': lat,
    'long': long
    }

# myLocation를 RTDB로 보내 객체 교체하기, patch는 특정 주소의 데이터가 변경됨
urequests.patch(url+"location.json", json = myLocation).json()
urequests.patch(mapUrl+"/"+nickname+".json", json = myLocation).json()
print("Location Info has been sent")
print()
time.sleep(0.5)

# OLED에 출력하기
oled.fill(0)
# 프레임버퍼로 로고 불러오기(이미지 사이즈는  32x32)
fb = framebuf.FrameBuffer(buffer, 32, 32, framebuf.MONO_HLSB)
# 프레임 버퍼에서 OLED 디스플레이로 이미지 옮기기
oled.blit(fb, 96, 0)
# 글자 넣기
oled.text("Location Info", 0, 25)
oled.text("has been sent", 0, 40)
# 이미지와 글자가 보여지도록 하기
oled.show()


# RTDB 내역 가져오기
response = urequests.get(url+".json").json()
# byte형태의 데이터를 json으로 변경했기 때문에 메모리를 닫아주는 일을 하지 않아도 됨
# print(response)
# print(response['smartFarm'])
# print(response['smartFarm']['led'])
time.sleep(0.5)


def fanAndPWM_control():
    while True:
        # Handling the fan based on temperature
        temperatureValue = round(sensor.temperature)
        db_fan_value = urequests.get(url + ".json").json()['smartFarm']['fan']
        time.sleep(0.5)

        if temperatureValue > temperatureStandardValue or db_fan_value == 1:
            fan.value(1)
        else:
            fan.value(0)

        # Handling the water pump based on moisture
        moistureValue = round(moisture.read_u16() / 65535 * 100)

        if moistureValue < moistureStandardValue:
            pwm.duty_u16(65025)  # 10% duty cycle
        else:
            pwm.duty_u16(0)

        time.sleep(1)
        
# 스레드를 시작합니다.
_thread.start_new_thread(fanAndPWM_control, ())


while True:
    # 현재 DB의 정보를 가져옴
    response = urequests.get(url+".json").json() # RTDB 데이터 가져오기
    time.sleep(0.5)
    
    # 현재 센서로부터 측정된 값을 가져옴
    humidityValue = round(sensor.relative_humidity) # 습도센서
    lightValue = round(100-((light.read_u16()/65535) * 100)) # 조도센서 값 읽어오기
    temperatureValue = round(sensor.temperature) # 온도센서 
    moistureValue = round(moisture.read_u16()/65535*100) # 수분센서 값 읽어오기
    
    # 현재시간 가져오기
    updatedTime = timeOfSeoul()
    # print(type(updatedTime))
    # print(updatedTime)
    # 읽어온 RTDB값과 센서 값 콘솔에 출력하기
    print("Status Check")
    print("updatedTime:", updatedTime,
          "LED:", response['smartFarm']['led'],
          "Fan:", response['smartFarm']['fan'],
          "Humidity:", humidityValue,
          "Light:", lightValue,
          "Temperature:", temperatureValue,
          "Moisture:", moistureValue)
    print()
    
    # OLED에 출력하기
    oled.fill(0)
    # 프레임버퍼로 로고 불러오기(이미지 사이즈는  32x32)
    fb = framebuf.FrameBuffer(buffer, 32, 32, framebuf.MONO_HLSB)
    # 프레임 버퍼에서 OLED 디스플레이로 이미지 옮기기
    oled.blit(fb, 96, 0)
    # 글자 넣기
    oled.text("Light: ", 0, 0)
    oled.text(str(round(lightValue,2)), 60, 0)
    oled.text("Temp: ", 0, 13)
    oled.text(str(round(temperatureValue,2)), 60, 13)
    oled.text("Humi: ", 0, 26)
    oled.text(str(round(humidityValue,2)), 60, 26)
    oled.text(str(updatedTime,2), 0, 39)
    # 현재 RTDB의 led 키 값의 상태에 따라 LED 핀(1번)을 제어
    if (response['smartFarm']['led'] == 0) :
        led.value(0)
        oled.text("LED Off", 5, 55)
    else :
        led.value(1)
        oled.text("LED On", 5, 55)
    # 현재 RTDB의 fan 키 값의 상태에 따라 Fan 핀(5번)을 제어
    if (response['smartFarm']['fan'] == 0) :
        fan.value(0)
        oled.text("Fan Off", 70, 55)
    else :
        fan.value(1)
        oled.text("Fan On", 70, 55)
    # OLED에 이미지와 글자가 보여지도록 하기
    oled.show()
    
    # 실시간으로 확인된 각 객체 값을 딕셔너리에 넣기
    myobj = {
        'updatedTime': updatedTime,
        'humi': humidityValue,
        'light': lightValue, 
        'temp': temperatureValue,
        'mois': moistureValue
        }
    
    # 실시간으로 확인된 각 객체 값을 딕셔너리에 넣기
    myobjGather = {
        'updatedTime': updatedTime,
        '-fan-': response['smartFarm']['fan'],
        '-led-': response['smartFarm']['led'],
        'humi': humidityValue,
        'light': lightValue,
        'temp': temperatureValue,
        'mois': moistureValue
        }
    
    # myobj를 RTDB로 보내 객체 값 교체하기, patch는 정해진 키값에 해당하는 데이터가 변경됨, post는 특정주소를 만들고 데이터를 누적시킴
    urequests.patch(url+"smartFarm.json", json = myobj).json()
    urequests.patch(mapUrl+"/"+nickname+"/"+"smartFarm.json", json = myobjGather).json()
    # 교체한 객체값 콘솔에 출력하기
    print("Message Send")
    print(myobj)
    print()
    
    time.sleep(0.5)
    

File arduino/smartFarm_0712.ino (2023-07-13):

#include <Wire.h> 
#include <LiquidCrystal_I2C.h>
#include <AHT10.h>

#define A_IA 5 // 모터드라이버 A_1A 단자 연결 핀번호(워터펌프)
#define A_IB 4 // 모터드라이버 A_1B 단자 연결 핀번호
#define B_IA 6 // 모터드라이버 B_1A 단자 연결 핀번호(팬)
#define B_IB 7 // 모터드라이버 B_1B 단자 연결 핀번호
#define SOIL_HUMI A0

LiquidCrystal_I2C lcd(0x27,20,4);  // LCD I2C 주소: 0x27
AHT10Class AHT10;

int cds_pin = A1; // 조도센서에 사용할 핀번호
int cds_ledpin = 13; // LED에 사용할 핀번호
int soil, psoil;  // 수분센서 값을 사용하기 위한 변수 선언
int val, cdsval, pcdsval; // 조도센서 값을 사용하기 위한 변수 선언
float t = 0;
float h = 0;
int waterpumpPower = 150;
int fanPower = 150;

void setup() {
  // AHT10 초기 설정
  Serial.begin(9600);
  Wire.begin();
  if(AHT10.begin(eAHT10Address_Low)) {
    Serial.println("Init AHT10 Success.");
  } else {
    Serial.println("Init AHT10 Failure.");
  }

  // LCD 초기 설정, 오프닝 이벤트    
  lcd.init();
  lcd.backlight();
  lcd.setCursor(0,0);
  lcd.print("Hello,SmartFarm!");
  lcd.setCursor(0,1);
  lcd.print("Made by M2Hands!");

  // 시리얼 통신 설정
  Serial.begin(9600); 
  Serial.println("Let's Go!");
  delay(1000);

   // 핀 설정 초기화
   pinMode(A_IA, OUTPUT); // 모터드라이브 출력모드
   pinMode(A_IB, OUTPUT);  
   analogWrite(A_IA, LOW); // 모터드라이브 초기값은 끈 상태
   analogWrite(A_IB, LOW);
   pinMode(B_IA, OUTPUT);
   pinMode(B_IB, OUTPUT);  
   analogWrite(B_IA, LOW);
   analogWrite(B_IB, LOW);
   pinMode(cds_ledpin,OUTPUT);
}

void loop() {
  t = AHT10.GetTemperature();
  h = AHT10.GetHumidity();

  soil = analogRead(SOIL_HUMI); // A0에서 읽은 값을 soil 변수에 저장
  psoil = map(soil, 1023, 0, 0, 100); // map함수를 사용하여 soil값을 1~100으로 변환한 값을 psoil에 저장
  val = analogRead(cds_pin); // A1에서 읽은 값을 val 변수에 저장
  cdsval = map(val,0, 1023, 250, 0); // map함수를 사용하여 val값을 1~250으로 변환한 값을 cdsval에 저장
  pcdsval = cdsval*0.4; // 조도센서값을 0~100으로 표시하기 위한 설정
  
  lcd.init(); // LCD 초기화 init() 명령이 안먹으면 begin으로 수정
  lcd.clear(); // 이전에 출력한 값 지우기 
  lcd.backlight(); // 배경화면 빛이 들어오도록 설정 
  lcd.display(); // 내용을 표시
  lcd.setCursor(0,0);
  lcd.print("M: "); //수분 M 
  lcd.print(psoil);
  lcd.print("%");
  lcd.setCursor(8,0);
  lcd.print("L: "); //조도 L
  lcd.print(pcdsval);  
  lcd.print("%");
  lcd.setCursor(0,1);
  lcd.print("T: "); //온도 T
  lcd.print(t,0);
  lcd.print("C");
  lcd.setCursor(8,1);
  lcd.print("H: "); //습도 H
  lcd.print(h,0);  
  lcd.print("%");

  Serial.print("수분: ");
  Serial.print(psoil);
  Serial.print("  조도: ");
  Serial.print(cdsval);
  Serial.print("  온도: ");
  Serial.print(t);
  Serial.print("  습도: ");
  Serial.print(h);
  Serial.println();
  delay(1000); 

  if(psoil < 30) { // 토양수분값이 30미만이면
    analogWrite(A_IA, waterpumpPower);  // 값을 변화시키면 서 호스에서 나오는 물의 양을 적정하게 설정
    digitalWrite(A_IB, LOW);    
  } else {  // 그 외 토양수분값이 측정되면 워터모터를 끄라
    digitalWrite(A_IA, LOW);
    digitalWrite(A_IB, LOW);
  } 
  if(t >= 20 || h >= 60) { // 온도가 20이상 또는 습도가 60이상이면,  || => [Shift] + [\]
    analogWrite(B_IA, fanPower);  // 값을 변화시키면서 팬의 세기를 설정(0~255)
    digitalWrite(B_IB, LOW);
  } else { // 그 외 온습도 측정값이면 미니모터를 끄라
    digitalWrite(B_IA, LOW);
    digitalWrite(B_IB, LOW);
  }
  if (pcdsval < 70) { // 조도센서값이 70미만이면
    digitalWrite(cds_ledpin, HIGH );   
  } else {  // 그 외 조도센서값이면 LED를 끄라
    digitalWrite(cds_ledpin, LOW);    
  }
}

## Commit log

2023-02-26 Rename 0. pico_test/timeRequest.py to 0. pico_test/11. timeRequest/timeRequest.py
2023-02-26 Rename timeRequest.py to timeRequest(whole code).py
2023-02-26 Update timeRequest(whole code).py
